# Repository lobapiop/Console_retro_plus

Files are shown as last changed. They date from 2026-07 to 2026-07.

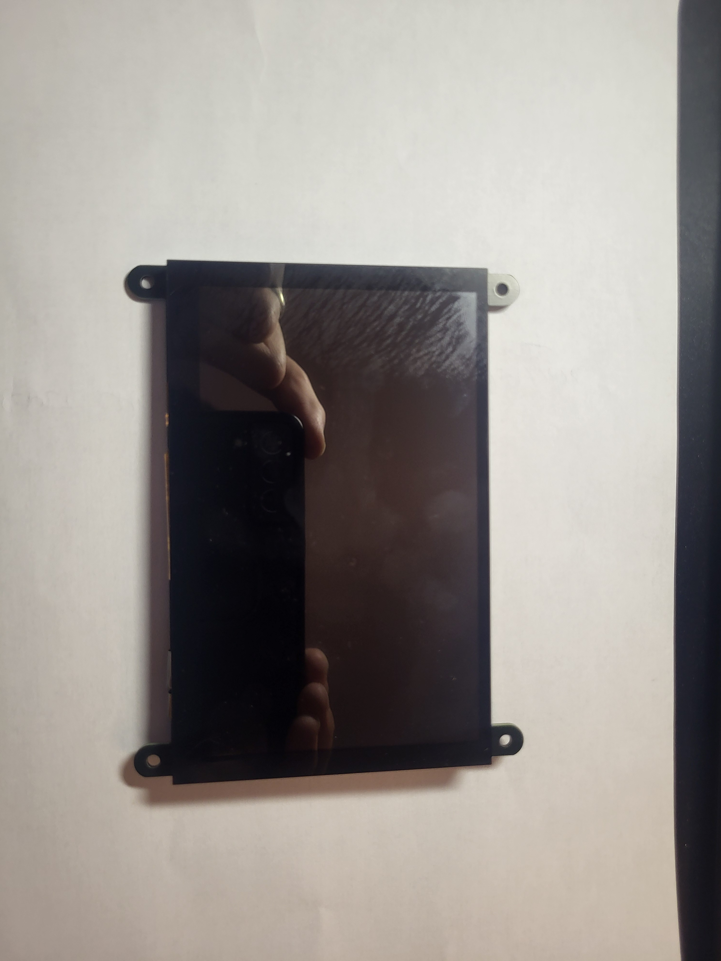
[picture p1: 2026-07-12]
Project-CRP/docs/08-Photos/ET001/face_avant_ecran.jpg

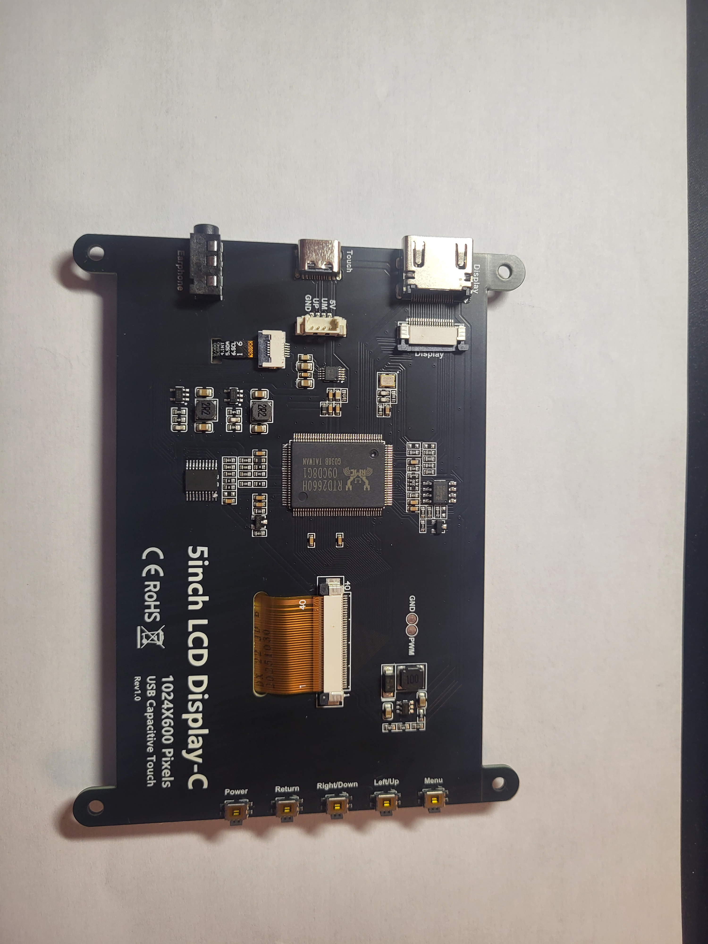
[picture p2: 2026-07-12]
Project-CRP/docs/08-Photos/ET001/face_arriere_ecran.jpg

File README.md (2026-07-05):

# Project CRP - Console Retro Plus

## Présentation

Project CRP (Console Retro Plus) est un projet open source ayant pour objectif de concevoir une console portable de rétrogaming basée sur un Raspberry Pi 5.

Le projet ne consiste pas simplement à intégrer un Raspberry Pi dans un boîtier imprimé en 3D. L'objectif est de développer une console portable fiable, ergonomique, maintenable et entièrement documentée.

Chaque décision de conception est justifiée, documentée et versionnée afin de permettre à toute personne de reproduire ou d'améliorer le projet.

---

## Objectifs

* Concevoir une console portable de qualité.
* Fournir une documentation complète.
* Utiliser des composants standards et facilement disponibles.
* Concevoir un boîtier robuste et facilement réparable.
* Centraliser tous les fichiers de conception dans un dépôt Git unique.
* Rendre le projet reproductible par la communauté.

---

## Caractéristiques principales

* Raspberry Pi 5 (4 Go)
* Écran IPS 5 pouces
* Batocera
* Wi-Fi et Bluetooth intégrés
* Dock HDMI + USB-C
* Recharge USB-C Power Delivery
* Batterie offrant environ 6 heures d'autonomie
* Deux joysticks Hall Effect
* D-Pad
* Boutons ABXY
* Gâchettes L1/L2 et R1/R2
* Haut-parleurs stéréo
* Prise casque 3,5 mm
* Microphone intégré
* Ventilateur intégré (gestion configurable)
* Boîtier imprimé en PETG
* Architecture orientée maintenance

---

## Philosophie du projet

Project CRP repose sur quelques principes simples :

* documenter chaque décision ;
* privilégier la qualité à la compacité ;
* rendre chaque pièce remplaçable ;
* limiter le câblage manuel au strict nécessaire ;
* utiliser des composants standard autant que possible.

---

## Méthodologie

Le projet est développé selon les étapes suivantes :

1. Cahier des charges
2. Architecture matérielle
3. Choix des composants (BOM)
4. Conception du boîtier
5. Conception électronique
6. Prototype
7. Validation
8. Documentation finale

Chaque étape est validée avant de passer à la suivante.

---

## Arborescence du projet

Le dépôt contient :

* documentation technique ;
* modèles 3D ;
* schémas électroniques ;
* PCB ;
* firmware ;
* configuration logicielle ;
* guides d'assemblage ;
* historique des décisions.

---

## État du projet

Version actuelle : Préparation du projet

Le cahier des charges est en cours de rédaction.

---

## Licence

À définir.

---

Projet développé dans un esprit de partage, d'apprentissage et de qualité.

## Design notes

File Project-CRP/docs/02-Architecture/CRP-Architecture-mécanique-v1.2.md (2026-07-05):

# Project CRP – Architecture mécanique

Version : 1.2

---

# 1. Objectif

Ce document définit l'architecture mécanique de Project CRP.

Il décrit :

* les dimensions cibles ;
* l'implantation générale des commandes ;
* les zones fonctionnelles internes ;
* les principes de maintenance ;
* les contraintes mécaniques.

Il constitue la référence avant la modélisation 3D.

---

# 2. Philosophie de conception

Project CRP privilégie :

* une excellente ergonomie ;
* une maintenance simple ;
* une architecture évolutive ;
* une conception robuste ;
* une documentation complète.

La compacité maximale n'est **pas** un objectif.

Le confort d'utilisation et la réparabilité sont prioritaires.

---

# 3. Règles CRP

## Règle n°1

Une architecture ne sera complexifiée que si un bénéfice technique clairement identifié le justifie.

Cela concerne notamment :

* le nombre de PCB ;
* le nombre de connecteurs ;
* le nombre de nappes ;
* les mécanismes particuliers.

---

## Règle n°2

Chaque élément extérieur de la console doit avoir une justification ergonomique ou fonctionnelle.

Son emplacement ne doit jamais être choisi uniquement pour des raisons esthétiques ou par imitation d'une autre console.

Avant de valider son implantation, les questions suivantes doivent être posées :

* est-il facilement accessible ?
* risque-t-il d'être actionné involontairement ?
* simplifie-t-il la maintenance ?
* simplifie-t-il la conception ?
* améliore-t-il l'expérience utilisateur ?

---

# 4. Dimensions cibles

Objectifs actuels :

* Largeur : 245 à 255 mm
* Hauteur : environ 110 mm
* Épaisseur : 25 à 30 mm (hors joysticks)

Poids cible :

* inférieur à 600 g

Ces dimensions pourront évoluer au cours du projet.

---

# 5. Implantation générale

## Façade

```text
┌────────────────────────────────────────────────────────────┐

        L1   L2                          R1   R2

                    Sortie d'air

 D-Pad                                   X   Y

 Stick G                               Stick D

               ┌───────────────────┐
               │                   │
               │   Écran IPS 5"    │
               │                   │
               └───────────────────┘

               Start        Select

────────────────────────────────────────────────────────────

 micro-HDMI   USB-C   Jack   Microphone

└────────────────────────────────────────────────────────────┘
```

Le dock utilisera uniquement les connecteurs situés sur la tranche inférieure.

---

# 6. Vue supérieure

```text
┌────────────────────────────────────────────────────────────┐

L1   L2

          microSD

          Power   ● LED RGB

          Volume +

          Volume -

                             R1   R2

└────────────────────────────────────────────────────────────┘
```

Le dessus de la console regroupe :

* le bouton Power ;
* la LED RGB ;
* les boutons Volume ;
* le lecteur microSD.

Cette disposition évite les appuis involontaires pendant le jeu.

---

# 7. Vue arrière

La face arrière comprend :

* les vis d'ouverture ;
* les entrées d'air ;
* le bouton RESET (accessible avec un trombone).

Le bouton RESET est destiné au développement et aux cas exceptionnels.

---

# 8. Architecture interne

L'organisation interne est définie par zones fonctionnelles.

De l'avant vers l'arrière :

1. coque avant ;
2. écran IPS ;
3. cartes de commandes ;
4. Raspberry Pi 5 ;
5. système de refroidissement ;
6. batterie LiPo ;
7. module d'alimentation ;
8. coque arrière.

Le nombre définitif de PCB sera déterminé ultérieurement.

---

# 9. Batterie

Objectifs :

* autonomie cible : environ 6 heures ;
* batterie remplaçable ;
* connecteur démontable ;
* remplacement sans dessoudage.

La batterie devra être centrée afin d'équilibrer le poids.

---

# 10. Refroidissement

Toutes les versions de Project CRP intégreront un ventilateur.

Le boîtier devra prévoir :

* une entrée d'air ;
* une sortie d'air ;
* un chemin d'air direct vers le Raspberry Pi.

Le ventilateur devra être facilement remplaçable.

Le contrôle intelligent de sa vitesse est une fonctionnalité logicielle optionnelle.

---

# 11. Connecteurs

## Face inférieure

* micro-HDMI
* USB-C Power Delivery
* Jack 3,5 mm
* Microphone

Tous les connecteurs sont regroupés afin de simplifier la conception du dock.

---

## Face supérieure

* Lecteur microSD
* Bouton Power
* LED RGB
* Volume +
* Volume -

---

## Face arrière

* RESET

---

# 12. LED RGB

Une seule LED RGB est utilisée.

Elle est placée à proximité du bouton Power.

Codes retenus :

* Bleu fixe : console allumée.
* Orange fixe : batterie en charge.
* Vert fixe : batterie complètement chargée.
* Rouge fixe : batterie faible.
* Rouge clignotant : batterie critique.
* Blanc bref : confirmation d'un appui sur Power.
* Éteinte : console éteinte (hors recharge).

Aucune LED Bluetooth n'est prévue.

Les informations Bluetooth seront affichées directement par Batocera.

---

# 13. Maintenance

Objectif :

Ouverture complète de la console en moins de cinq minutes.

Ordre souhaité :

1. retirer les vis arrière ;
2. ouvrir la coque ;
3. débrancher la batterie ;
4. accéder immédiatement aux principaux composants.

Les éléments suivants devront être remplaçables :

* batterie ;
* Raspberry Pi ;
* ventilateur ;
* écran ;
* joysticks ;
* haut-parleurs.

Le démontage ne devra nécessiter aucun collage.

---

# 14. Fixations

Le boîtier utilisera :

* des vis métriques standard ;
* des inserts filetés en laiton.

Le collage sera évité autant que possible.

---

# 15. Cheminement des câbles

Les câbles devront :

* être les plus courts possible ;
* être guidés dans des logements dédiés ;
* ne pas gêner la circulation de l'air ;
* ne jamais être pincés lors de la fermeture du boîtier.

---

# 16. Dock

Le dock est volontairement simple.

Fonctions :

* alimentation USB-C ;
* sortie HDMI ;
* LED de présence d'alimentation.

Aucun port USB supplémentaire n'est prévu dans la première version.

---

# 17. Évolutivité

L'architecture devra permettre ultérieurement :

* un changement de batterie ;
* un changement de ventilateur ;
* un RP2040 intégré sur PCB ;
* une évolution du dock.

---

# 18. Points restant à valider

Les éléments suivants seront définis lors des études techniques :

* référence exacte de l'écran ;
* référence de la batterie ;
* référence des joysticks Hall Effect ;
* référence du ventilateur ;
* architecture définitive des PCB.

Aucune décision sur le nombre final de PCB ne sera prise avant la fin des études techniques.

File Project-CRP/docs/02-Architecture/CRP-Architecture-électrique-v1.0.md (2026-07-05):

# Project CRP - Architecture électrique

Version : 1.0

---

# 1. Objectif

Ce document décrit l'architecture électrique générale de Project CRP.

Il définit les différents modules électriques, leurs responsabilités ainsi que les interfaces de communication entre eux.

Il ne constitue pas un schéma électronique mais la référence fonctionnelle qui guidera la conception des futurs PCB.

---

# 2. Vue d'ensemble

```text
                        Chargeur USB-C PD
                               │
                               ▼
                     Module Power / BMS
                               │
             ┌─────────────────┴──────────────────┐
             │                                    │
             ▼                                    ▼
      Batterie LiPo                    Alimentation 5V
             │                                    │
             │                              Raspberry Pi 5
             │                                    │
             │        ┌───────────────────────────┼─────────────────────────────┐
             │        │                           │                             │
             ▼        ▼                           ▼                             ▼
        Jauge batterie RP2040                 HDMI                       USB / GPIO
                 │                             │                             │
                 │                             ▼                             ▼
                 │                       Écran IPS                     Audio / Entrées
                 │
                 ▼
         LED - Ventilateur
         Bouton Power
```

---

# 3. Sous-systèmes

## 3.1 Module Power

Responsabilités :

* réception de l'alimentation USB-C ;
* négociation USB-C Power Delivery ;
* recharge de la batterie ;
* alimentation simultanée du système et de la batterie (Power Path) ;
* protections électriques.

Ce module constitue le cœur de l'alimentation de la console.

---

## 3.2 Batterie

Objectifs :

* batterie LiPo remplaçable ;
* autonomie cible : 6 heures ;
* connecteur démontable.

Le choix définitif de la capacité sera réalisé lors de la BOM.

---

## 3.3 Raspberry Pi 5

Le Raspberry Pi assure :

* Batocera ;
* les émulateurs ;
* le réseau ;
* la vidéo ;
* l'audio logiciel.

Le Raspberry Pi ne pilote pas directement l'alimentation générale.

---

## 3.4 RP2040

Le RP2040 est le contrôleur matériel.

Il reste alimenté indépendamment du Raspberry Pi.

Il pilote notamment :

* bouton Power ;
* LED d'état ;
* ventilateur ;
* surveillance batterie ;
* démarrage et arrêt du Raspberry Pi.

Prototype V0 :

* Raspberry Pi Pico.

Version V1/V2 :

* RP2040 intégré au PCB principal.

---

## 3.5 Écran

Connexion :

HDMI

Alimentation :

5 V

L'écran est indépendant du RP2040.

---

## 3.6 Audio

Comprend :

* amplificateur ;
* deux haut-parleurs ;
* prise jack ;
* microphone.

Le détail de l'architecture audio sera défini dans une version ultérieure.

---

## 3.7 Ventilateur

Ventilateur 5 V.

Piloté par le RP2040.

La vitesse pourra être :

* fixe ;
* automatique ;
* configurable.

---

# 4. Interfaces

| Interface | Utilisation |
| --- | --- |
| HDMI | Écran interne |
| micro-HDMI | Téléviseur |
| USB-C PD | Recharge |
| GPIO | Commandes |
| UART (prévu) | Communication Pi ↔ RP2040 |
| I²C (prévu)  | Capteurs éventuels |
| PWM | Ventilateur |
| I²S ou USB | Audio (à confirmer) |

---

# 5. Démarrage

1. Appui sur Power.
2. Le RP2040 active l'alimentation principale.
3. Le Raspberry Pi démarre.
4. Le RP2040 surveille le système.
5. Les LED indiquent l'état de fonctionnement.

---

# 6. Arrêt

1. Appui sur Power.
2. Le RP2040 demande un arrêt propre au Raspberry Pi.
3. Le Raspberry Pi s'éteint.
4. Le RP2040 coupe l'alimentation principale.

En cas de blocage :

* un appui long forcera l'extinction.

---

# 7. Recharge

Le système devra permettre :

* recharge console éteinte ;
* recharge console allumée ;
* utilisation pendant la recharge ;
* branchement ou débranchement du chargeur sans extinction.

---

# 8. Dock

Le dock est entièrement passif.

Il fournit :

* alimentation USB-C ;
* sortie HDMI ;
* LED de présence d'alimentation.

Aucun composant actif n'est prévu dans la première version.

---

# 9. Maintenance

Tous les modules devront être indépendants.

Les éléments suivants devront pouvoir être remplacés sans dessoudage :

* batterie ;
* écran ;
* Raspberry Pi ;
* ventilateur ;
* haut-parleurs.

Les connecteurs seront privilégiés lorsque cela est possible.

---

# 10. Évolutions prévues

Les éléments suivants pourront être ajoutés ultérieurement :

* jauge de batterie avancée ;
* profils de ventilation ;
* mode veille amélioré ;
* dock intelligent ;
* intégration complète du RP2040 sur PCB.

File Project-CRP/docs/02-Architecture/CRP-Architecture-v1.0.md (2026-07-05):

# Project CRP - Architecture

Version : 1.0

---

# 1. Objectif

Ce document décrit l'architecture générale de Project CRP.

Il définit les principaux sous-systèmes de la console ainsi que leurs interactions.

L'objectif est de garantir une architecture modulaire, facilement maintenable et évolutive.

---

# 2. Vue d'ensemble

```
                        +----------------------+
                        |    Raspberry Pi 5    |
                        |        4 Go          |
                        +----------+-----------+
                                   |
        +------------+-------------+-------------+--------------+
        |            |             |             |              |
        |            |             |             |              |
     HDMI        USB 2.0        GPIO        Bluetooth       Wi-Fi
        |            |             |
        |            |             |
        |        RP2040        Boutons
        |            |
        |            |
        |     Batterie / LEDs
        |
    Ecran IPS
```

Le Raspberry Pi constitue le cœur du système.

Tous les éléments périphériques sont organisés autour de lui.

---

# 3. Modules principaux

## Module de calcul

Fonction :

* exécuter Batocera ;
* faire fonctionner les émulateurs ;
* gérer l'affichage ;
* gérer les communications réseau.

Composant principal :

* Raspberry Pi 5 (4 Go)

---

## Module d'affichage

Fonction :

* affichage principal de la console.

Caractéristiques :

* écran IPS 5 pouces ;
* interface HDMI.

L'écran devra être facilement remplaçable.

---

## Module de commande

Fonction :

* lecture des commandes utilisateur.

Il comprend :

* D-Pad
* ABXY
* Start
* Select
* Volume
* Power
* L1
* L2
* R1
* R2
* deux joysticks Hall Effect

Les commandes seront regroupées sur un ou plusieurs PCB dédiés.

---

## Module audio

Fonction :

* restitution sonore.

Il comprend :

* deux haut-parleurs ;
* une prise casque 3,5 mm ;
* un microphone.

---

## Module alimentation

Fonction :

* alimentation de la console ;
* recharge de la batterie ;
* alimentation pendant la recharge ;
* protection électrique.

Il devra fonctionner de manière totalement transparente pour l'utilisateur.

---

## Module batterie

Objectifs :

* autonomie cible : environ 6 heures ;
* batterie facilement remplaçable ;
* connecteur démontable.

La capacité exacte sera définie ultérieurement.

---

## Module ventilation

Fonction :

* refroidissement du Raspberry Pi.

Le ventilateur sera présent sur toutes les versions.

Le contrôle intelligent restera optionnel.

---

## Module Dock

Fonctions :

* recharge ;
* alimentation ;
* sortie HDMI vers le téléviseur.

Le dock restera volontairement simple.

---

## Module RP2040

Le RP2040 constitue le contrôleur embarqué de la console.

Il sera indépendant du Raspberry Pi.

Fonctions envisagées :

* gestion du bouton Power ;
* surveillance de la batterie ;
* contrôle des LED ;
* contrôle du ventilateur ;
* gestion des sécurités d'alimentation.

Cette architecture permet au Raspberry Pi de rester concentré sur l'émulation.

## Stratégie d'intégration du RP2040

Le RP2040 est retenu comme contrôleur matériel de Project CRP.

Il assurera les fonctions suivantes :

* gestion du bouton Power ;
* extinction propre du Raspberry Pi ;
* contrôle des LED ;
* surveillance de la batterie ;
* contrôle du ventilateur ;
* détection du dock ;
* gestion de certaines sécurités matérielles.

### Prototype V0

Pour le premier prototype, le projet utilisera un **Raspberry Pi Pico** complet.

Ce choix permet :

* de réduire la complexité électronique initiale ;
* de faciliter les tests ;
* de remplacer facilement le module en cas d'erreur ;
* de simplifier le développement du firmware.

### Version V1 / V2

Une fois les fonctions validées, le RP2040 pourra être intégré directement sur un PCB dédié CRP.

Ce choix permettra :

* de réduire l'encombrement ;
* de limiter le câblage ;
* d'améliorer la fiabilité ;
* de rendre l'intégration plus propre.

Cette évolution ne sera réalisée qu'après validation complète du prototype.

---

# 4. Implantation générale

Vue simplifiée :

```
 ___________________________________________

   L1 L2                         R1 R2

+-------------------------------------------+

|                                           |
|               Ecran IPS 5"                |
|                                           |

| DPad                      X  Y            |
|                           A  B            |

| Stick G        Start  Select     Stick D  |

+-------------------------------------------+

| micro-HDMI | USB-C | Jack | Microphone    |

---------------------------------------------
```

Le Raspberry Pi sera implanté derrière l'écran.

La batterie sera placée derrière le Raspberry Pi.

Les cartes boutons seront situées de chaque côté.

---

# 5. Philosophie de maintenance

Toutes les pièces devront être remplaçables.

Ordre de démontage souhaité :

1. Retrait de la coque arrière.
2. Déconnexion de la batterie.
3. Accès au Raspberry Pi.
4. Accès aux haut-parleurs.
5. Accès aux joysticks.
6. Accès aux cartes boutons.

Aucune pièce ne devra être collée.

---

# 6. Architecture logicielle

Le Raspberry Pi exécutera :

* Batocera ;
* les émulateurs ;
* l'interface utilisateur.

Le RP2040 exécutera :

* la gestion matérielle ;
* le contrôle du ventilateur ;
* la surveillance de la batterie ;
* les LED.

Les deux systèmes communiqueront via une interface série (UART) ou USB, à déterminer lors de la conception électronique.

---

# 7. Évolutivité

L'architecture doit permettre :

* le remplacement de la batterie ;
* le remplacement de l'écran ;
* le remplacement des joysticks ;
* l'évolution du firmware RP2040 ;
* l'amélioration du dock.

---

# 8. Principes retenus

Le projet suit les principes suivants :

* simplicité ;
* robustesse ;
* modularité ;
* maintenance ;
* documentation complète.

Chaque sous-système devra pouvoir être testé indépendamment avant l'assemblage final.

---

# 9. Travaux suivants

Les prochaines étapes seront :

* choix des composants ;
* définition du système batterie ;
* définition du système audio ;
* définition des connecteurs ;
* conception du boîtier 3D ;
* réalisation de la nomenclature officielle (BOM).

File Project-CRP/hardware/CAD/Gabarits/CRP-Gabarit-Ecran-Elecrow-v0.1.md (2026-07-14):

# Objectif du gabarit :

Créer une représentation mécanique simplifiée mais dimensionnellement fiable du module écran Elecrow afin de préparer son intégration dans Project CRP.

Le gabarit sert à valider l’encombrement, les fixations, la zone visible, les connecteurs, les nappes fragiles et les volumes de dégagement nécessaires avant toute conception de coque complète.

Module complet : 121,31 × 95,47 × 10 mm
Rectangle écran physique : 121,31 × 75,65 mm
Zone active visible : environ 108 × 64,8 mm
Trous de fixation : Ø 3 mm
Trous hauts : environ Y = 5 mm
Trous bas : environ Y = 91 mm
Profondeur de réservation avec câbles droits : 65 mm
Câbles coudés nécessaires : oui
Zones FPC : à protéger

1. créer le gabarit 2D simple du module ;
2. placer les quatre trous de fixation ;
3. placer la zone écran visible ;
4. ajouter les volumes interdits pour les connecteurs ;
5. ajouter les zones fragiles FPC ;
6. extruder en volume simple 3D ;
7. vérifier si ça rentre dans l’enveloppe CRP cible ;
8. documenter les réserves.

# Données 
Module complet :
121,31 mm × 95,47 mm × 10 mm

Rectangle écran physique :
121,31 mm × 75,65 mm

Zone active visible :
environ 108 mm × 64,8 mm

Trous de fixation :
diamètre 3 mm

Positions des trous :
T1 : X = 5 mm, Y = 5 mm
T2 : X = 117,57 mm, Y = 5 mm
T3 : X = 5 mm, Y = 91 mm
T4 : X = 117,57 mm, Y = 91 mm

# Repère

Origine = coin supérieur gauche du module
X = vers la droite
Y = vers le bas
Z = épaisseur

T1 haut gauche : X = 5 mm, Y = 95,47 - 5 = 90,47 mm
T2 haut droit : X = 117,57 mm, Y = 90,47 mm
T3 bas gauche : X = 5 mm, Y = 95,47 - 91 = 4,47 mm
T4 bas droit : X = 117,57 mm, Y = 4,47 mm

Position verticale de la zone écran physique à confirmer

| Élément | Mesure |
|---|---:|
| Largeur totale avec pattes | 121,31 mm |
| Hauteur totale avec pattes | 95,47 mm |
| Largeur corps principal sans pattes | 121,31 mm |
| Hauteur corps principal sans pattes | 78 mm |
| Dépassement patte gauche | 9 mm |
| Dépassement patte droite | 9 mm |
| Dépassement patte haute | 9 mm |
| Dépassement patte basse | 9 mm |
| Largeur d’une patte | 7.5 mm |
| Diamètre trou fixation | 3 mm |

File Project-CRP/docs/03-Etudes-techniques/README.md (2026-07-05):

# Études techniques

Ce dossier regroupe les études techniques de conception du projet Project CRP.

## Index des études

| Ordre | Étude | Fichier | Statut |
| ----- | ----- | --- | --- |
| ET001 | Écran | [ET001-Ecran.md](ET001-Ecran.md) | à faire |
| ET002 | Ergonomie et commandes | [ET002-Ergonomie-commandes.md](ET002-Ergonomie-commandes.md) | à faire |
| ET003 | Implantation mécanique | [ET003-Implantation-mecanique.md](ET003-Implantation-mecanique.md) | à faire |
| ET004 | Batterie et alimentation | [ET004-Batterie-alimentation.md](ET004-Batterie-alimentation.md) | à faire |
| ET005 | Audio | [ET005-Audio.md](ET005-Audio.md) | à faire |
| ET006 | Refroidissement | [ET006-Refroidissement.md](ET006-Refroidissement.md) | à faire |
| ET007 | RP2040 | [ET007-RP2040.md](ET007-RP2040.md) | à faire |
| ET008 | Dock | [ET008-Dock.md](ET008-Dock.md) | à faire |

## Notes

- Les études sont prévues pour évoluer au fur et à mesure du prototypage.
- Les fichiers peuvent être enrichis avec des schémas, mesures et décisions de conception.

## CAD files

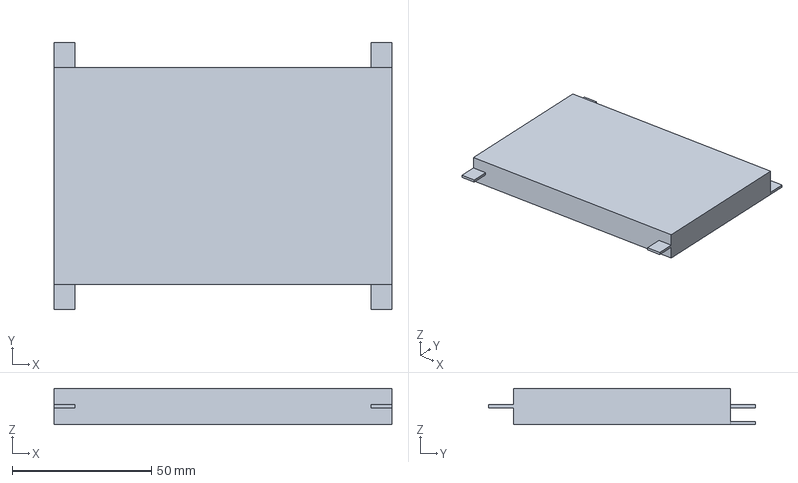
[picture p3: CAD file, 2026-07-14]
Project-CRP/hardware/CAD/Gabarits/CRP-Gabarit-Ecran-Elecrow.FCStd
121.3 x 96.0 x 13.0 mm

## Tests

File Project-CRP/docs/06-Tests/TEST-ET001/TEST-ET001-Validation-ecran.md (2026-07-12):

# Project CRP – TEST-ET001 – Validation du module d’affichage

Version : 0.1  
Statut : à finalisé après l'arrivé du test USB
Étude associée : ET001 – Module d’affichage  
Composant testé : Elecrow 5inch IPS HD Display-C 1024×600  
Référence attendue : DLH04950B  
Plateforme : Raspberry Pi 5 – 4 Go  
Système : Batocera  

---

# 1. Objet

Ce document définit le protocole de validation du module d’affichage Elecrow retenu comme candidat prioritaire pour Project CRP.

L’objectif est de vérifier expérimentalement :

- la conformité du produit reçu ;
- sa compatibilité avec le Raspberry Pi 5 ;
- sa compatibilité avec Batocera ;
- la qualité réelle de l’affichage ;
- la stabilité de fonctionnement ;
- le fonctionnement du tactile ;
- le comportement de la sortie TV ;
- son intégration mécanique préliminaire ;
- son aptitude à devenir l’écran définitif de Project CRP.

La validation finale de l’écran ne doit pas reposer uniquement sur les caractéristiques commerciales ou les avis disponibles.

---

# 2. Périmètre

Le présent protocole couvre :

- l’inspection visuelle du module ;
- le relevé des références ;
- le premier branchement ;
- le premier démarrage ;
- la détection de la résolution ;
- l’utilisation de Batocera ;
- l’affichage des jeux rétro ;
- l’émulation Nintendo DS ;
- le tactile ;
- la sortie HDMI vers un téléviseur ;
- la stabilité thermique ;
- la consommation de l’écran, si un appareil de mesure est disponible ;
- les principales dimensions mécaniques.

Le protocole ne couvre pas encore :

- l’alimentation sur batterie ;
- l’autonomie finale de la console ;
- l’intégration dans la coque ;
- l’électronique de gestion d’alimentation ;
- le dock définitif ;
- la carte de commandes ;
- l’audio définitif de la console.

---

# 3. Critères de décision

À la fin des essais, le module recevra l’un des statuts suivants :

| Statut | Signification |
|---|---|
| Validé | Le module répond aux exigences principales de Project CRP |
| Validé sous réserve | Le module est utilisable, mais des limitations restent à traiter |
| Test complémentaire requis | Les résultats sont insuffisants pour prendre une décision |
| Rejeté | Le module présente une incompatibilité ou une contrainte majeure |

Un défaut critique entraîne normalement le rejet du module.

Exemples de défauts critiques :

- absence d’affichage sous Batocera ;
- image instable ou fortement déformée ;
- impossibilité d’utiliser la résolution native ;
- panne après échauffement ;
- encombrement mécanique incompatible ;
- câblage interne irréalisable ;
- incompatibilité majeure avec la sortie TV.

---

# 4. Matériel nécessaire

## 4.1 Matériel principal

| Élément | Requis | Disponible | Remarque |
|---|---|---|---|
| Raspberry Pi 5 – 4 Go | Oui |  | Plateforme cible CRP |
| Refroidisseur actif pour Raspberry Pi 5 | Oui |  | À installer avant les tests prolongés |
| Alimentation USB-C adaptée au Pi 5 | Oui |  | Alimentation officielle recommandée |
| Carte microSD | Oui |  | 64 Go minimum recommandé |
| Batocera compatible Raspberry Pi 5 | Oui |  | Version à noter |
| Écran Elecrow 5 pouces 1024×600 | Oui |  | Référence à confirmer |
| Câble micro-HDMI vers HDMI | Oui |  | Pour l’écran |
| Câble USB-A vers USB-C | Oui |  | Alimentation et éventuellement tactile |
| Chargeur USB 5 V | Oui |  | 1 A minimum, 2 A recommandé |
| Manette PS4 ou PS5 | Oui |  | Connexion USB pour le premier test |
| Téléviseur ou moniteur HDMI | Pour test TV |  |  |
| Second câble micro-HDMI vers HDMI | Pour test TV |  |  |

## 4.2 Matériel de mesure facultatif

| Élément | Utilité |
|---|---|
| Pied à coulisse | Mesure des dimensions du module |
| Règle métallique | Contrôle approximatif des dimensions |
| Testeur USB | Mesure de la tension, du courant et de la puissance |
| Multimètre | Vérifications électriques complémentaires |
| Thermomètre infrarouge | Mesure approximative des températures |
| Appareil photo ou téléphone | Documentation du test |

---

# 5. Informations générales du test

| Information | Valeur |
|---|---|
| Date du test | 2026-07-12 |
| Testeur | Lobapiop |
| Version de Batocera | batocera-bcm2712-43.1-20260529 |
| Modèle du Raspberry Pi | PI 5 |
| Quantité de mémoire | 4Gbi |
| Référence de l’écran | QDtech MPI5001 |
| Référence indiquée sur le PCB |  |
| Référence indiquée sur l’emballage | 5inch HD Diplay-C |
| Type de carte microSD | 64go |
| Type d’alimentation du Pi | Origine |
| Type d’alimentation de l’écran | Origine |
| Téléviseur utilisé | MSI optix MAG241CV |
| Version du firmware Raspberry Pi, si disponible |  |

---

# 6. Précautions

Avant tout branchement :

1. poser le Raspberry Pi et l’écran sur une surface non conductrice ;
2. ne pas poser les cartes électroniques sur du métal ;
3. installer le refroidisseur actif sur le Raspberry Pi ;
4. vérifier l’orientation des connecteurs ;
5. effectuer les branchements hors tension ;
6. ne pas forcer les prises HDMI ou USB-C ;
7. éviter de toucher directement les composants lorsque le système est alimenté ;
8. ne pas placer d’objet conducteur sous les cartes ;
9. vérifier que le chargeur de l’écran fournit une tension de 5 V ;
10. ne pas utiliser de câble visiblement endommagé.

Pour les premiers essais, le Raspberry Pi et l’écran doivent être alimentés séparément.

---

# 7. Schéma de branchement initial

```text
Alimentation officielle USB-C
            │
            ▼
     Raspberry Pi 5
            │
            │ micro-HDMI vers HDMI
            ▼
      Écran Elecrow

Chargeur USB 5 V
            │
            │ USB-A vers USB-C
            ▼
      Écran Elecrow

Manette PS4 ou PS5
            │
            │ USB
            ▼
     Raspberry Pi 5
```

# 8.Décision :

L’écran Elecrow 5 pouces 1024×600 est retenu comme candidat prioritaire pour Project CRP.

Statut :

Validé sous réserve.

Score après essais :

8,2 / 10.

Réserves restantes :

- consommation électrique réelle non mesurée ;
- câbles droits incompatibles avec la coque cible ;
- câbles coudés ou adaptation interne nécessaires ;
- protection obligatoire des nappes FPC ;
- validation mécanique finale à réaliser dans FreeCAD.

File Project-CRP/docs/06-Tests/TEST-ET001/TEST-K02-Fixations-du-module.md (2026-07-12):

# Project CRP – TEST-K02 – Fixations du module

Version : 0.1  
Statut : réalisé
Étude associée : ET001 – Module d’affichage  
Composant testé : Elecrow 5inch IPS HD Display-C 1024×600  
Référence attendue : DLH04950B  
Plateforme : Raspberry Pi 5 – 4 Go  
Système : Batocera  

---

## 1. Objectif

Relever les trous et entraxes nécessaires au montage mécanique.

## 2. Procédure

1. Numéroter les trous.
2. Mesurer leur diamètre.
3. Mesurer les entraxes horizontaux et verticaux.
4. Mesurer leur distance aux bords de référence.
5. Photographier le module avec les points repérés.

## 3. Résultats

T1 = trou haut gauche
T2 = trou haut droit
T3 = trou bas gauche
T4 = trou bas droit

Diamètre trou T1 : 3 mm
Diamètre trou T2 : 3 mm
Diamètre trou T3 : 3 mm
Diamètre trou T4 : 3 mm

Entraxe horizontal supérieur : T1 → T2
Entraxe horizontal inférieur : T3 → T4
Entraxe vertical gauche : T1 → T3
Entraxe vertical droit : T2 → T4

| Élément | Mesure |
|---|---:|
| Entraxe horizontal supérieur | 112.75 mm |
| Entraxe horizontal inférieur | 112.75 mm |
| Entraxe vertical gauche | 85.33 mm |
| Entraxe vertical droit | 85.33 mm |

T1 : centre à 5 mm du bord gauche, 5 mm du bord supérieur
T2 : centre à 117.57 mm du bord gauche, 5 mm du bord supérieur
T3 : centre à 5 mm du bord gauche, 91 mm du bord supérieur
T4 : centre à 117.57 mm du bord gauche, 91 mm du bord supérieur

Y a-t-il un composant proche ? non tout est à l'extérieur
Y a-t-il assez de place pour une tête de vis ? oui
Y a-t-il assez de place pour une entretoise ? oui
Le trou est-il métallisé ? non c'est du PCB
Le trou traverse-t-il seulement le PCB ? Oui
La vis risque-t-elle de toucher un composant ? Non

## 4. Observations

- présence d’inserts :  Non
- possibilité d’utiliser des entretoises :  oui
- zone libre autour des trous :  Oui
- risque de contact avec des composants :  Non

## 5. Conclusion

Fixations directement utilisables : Oui 

Remarques :

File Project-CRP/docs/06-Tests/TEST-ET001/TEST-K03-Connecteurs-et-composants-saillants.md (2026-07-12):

# Project CRP – TEST-K03 – Connecteurs et composants saillants

Version : 0.1  
Statut : réalisé
Étude associée : ET001 – Module d’affichage  
Composant testé : Elecrow 5inch IPS HD Display-C 1024×600  
Référence attendue : DLH04950B  
Plateforme : Raspberry Pi 5 – 4 Go  
Système : Batocera  

---

## 1. Objectif

Déterminer les volumes à réserver autour des connecteurs, boutons et composants arrière.

## 2. Procédure

1. Repérer chaque connecteur.
2. Mesurer sa position depuis deux bords de référence.
3. Mesurer son débord.
4. Brancher les câbles sans alimenter le système.
5. estimer le rayon de courbure et le dégagement nécessaire.

## 3. Résultats

| Connecteur | Débord rigide avec câble branché | Rayon de courbure estimé | Dégagement recommandé |
|---|---:|---:|---:|
| USB-C écran | 40 mm | 10 mm | 55 mm |
| HDMI | 40 mm | 20 mm | 65 mm |
| Jack audio  | 40 mm | 10 mm | 55 mm |
| Connecteur FPC |  |  |  |
| Boutons OSD |  |  |  |
| Composant le plus haut |  |  |  |

## 4. Câblage

| Câble | Connecteur droit/coudé | Rayon minimal observé | Compatible avec la coque cible |
|---|---|---:|---|
| HDMI | Droit | 20mm |  Non  |
| USB-C | Droit | 10mm |  Non |
| Audio | Droit | 10mm  |  Non |

## 5. Conclusion

Profondeur de réservation recommandée :

`65 mm`

Câbles coudés nécessaires : Oui 

Remarques :

Connecteur FPC principal dalle LCD : Oui
Position : centre-bas de la carte
Nappe présente : Oui, nappe orange large
Risque mécanique : élevé
Remarque : ne pas plier fortement, ne pas écraser, prévoir un dégagement dans la coque.

Connecteur FPC Display secondaire : Oui
Position : sous le connecteur HDMI
Nappe présente : Non
Risque mécanique : moyen à élevé
Remarque : zone à protéger, proche du connecteur HDMI.

Petit connecteur FPC secondaire : Oui
Position : partie haute-gauche de la carte, sous la zone earphone / touch
Nappe présente : Oui
Risque mécanique : moyen
Remarque : petite nappe fragile, ne pas mettre en contrainte.

## Connecteurs FPC observés

| Élément | Présence | Position | Remarque |
|---|---|---|---|
| FPC principal dalle LCD | Oui | centre-bas de la carte | grande nappe orange, zone critique |
| FPC Display secondaire | Oui | sous le connecteur HDMI | proche du HDMI, à protéger |
| Petit FPC secondaire | Oui | haut-gauche / zone Touch | petite nappe fragile |
| Connecteur 5V/Uart/GND | Non FPC | haut-centre | connecteur filaire, probablement JST |
| Boutons OSD | Non FPC | bord bas | boutons physiques de réglage écran |

Conclusion :

Le module comporte plusieurs nappes FPC visibles. Ces zones sont mécaniquement sensibles et devront être protégées dans la future coque. Aucun appui direct de la coque, d’une entretoise ou d’un câble ne devra être exercé sur les nappes ou sur leurs connecteurs.

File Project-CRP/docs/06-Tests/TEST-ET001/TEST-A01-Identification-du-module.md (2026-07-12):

# Project CRP – TEST-A01 – Identification du module

Version : 0.1  
Statut : réalisé 
Étude associée : ET001 – Module d’affichage  
Composant testé : Elecrow 5inch IPS HD Display-C 1024×600  
Référence attendue : DLH04950B  
Plateforme : Raspberry Pi 5 – 4 Go  
Système : Batocera  

---

## 1. Objectif

Vérifier que le produit reçu correspond au module commandé et qu’il ne présente aucun dommage visible.

## 2. Matériel nécessaire

- module Elecrow reçu ; 
- emballage et accessoires ; 
- téléphone ou appareil photo ;
- plan ou fiche produit disponible.

## 3. Procédure

1. Ne pas alimenter le module.
2. Photographier l’emballage, la face avant, la face arrière et les connecteurs.
3. Relever toutes les références présentes sur l’emballage et le PCB.
4. Vérifier visuellement la dalle, le PCB, les connecteurs et les nappes.
5. Comparer le contenu reçu avec la commande.

## 4. Résultats

| Contrôle | Observation | Conforme |
|---|---|---|
| Marque Elecrow présente |  | Oui  |
| Diagonale annoncée de 5 pouces |  | Oui |
| Résolution annoncée de 1024×600 |  | Oui |
| Référence DLH04950B présente |  |  Non trouvée |
| Entrée HDMI présente |  | Oui  |
| Connecteur USB-C présent |  | Oui |
| Tactile présent |  | Oui / Non |
| PCB sans dommage visible |  | Oui  |
| Dalle sans fissure |  | Oui  |
| Connecteurs non déformés |  | Oui |
| Accessoires conformes |  | Oui  |

## 5. Critères de réussite

- aucun dommage visible ;
- connecteurs intacts ;
- caractéristiques principales conformes ;
- absence d’erreur évidente de modèle.

## 6. Conclusion

Résultat :  Ok

Références relevées :

Remarques : Je n'ai pas trouvé la référence. 

Photos associées :

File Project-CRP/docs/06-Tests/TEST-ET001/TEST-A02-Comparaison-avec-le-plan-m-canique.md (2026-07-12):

# Project CRP – TEST-A02 – Comparaison avec le plan mécanique

Version : 0.1  
Statut : réalisé  
Étude associée : ET001 – Module d’affichage  
Composant testé : Elecrow 5inch IPS HD Display-C 1024×600  
Référence attendue : DLH04950B  
Plateforme : Raspberry Pi 5 – 4 Go  
Système : Batocera  

---

## 1. Objectif

Déterminer si le plan mécanique précédemment trouvé correspond réellement au module reçu.

## 2. Matériel nécessaire

- module Elecrow ;
- plan mécanique trouvé ;
- règle ou pied à coulisse ;
- appareil photo.

## 3. Procédure

1. Comparer la forme générale du PCB.
2. Comparer la position et l’orientation des connecteurs.
3. Compter les boutons et les trous de fixation.
4. Comparer les dimensions générales.
5. Photographier chaque différence.

## 4. Résultats

| Élément comparé | Identique | Différent | Remarque |
|---|---|---|---|
| Forme générale du PCB | Identique |  |  |
| Position du port HDMI | Identique |  |  |
| Position du port USB-C | Identique |  |  |
| Nombre de boutons | Identique |  |  |
| Position des boutons | Identique |  |  |
| Nombre de trous de fixation | Identique |  |  |
| Position des trous | Identique |  |  |
| Forme des composants arrière | Identique |  |  |
| Dimensions générales | Identique |  |  |

## 5. Décision documentaire

Plan correspondant au produit :

- [X] Oui, correspondance confirmée
- [ ] Correspondance partielle
- [ ] Non, modèle différent
- [ ] Impossible à déterminer

Plan utilisable pour FreeCAD :

- [ ] Oui
- [ ] Non
- [X] Seulement après correction

## 6. Conclusion

Résultat : Réussi 

Corrections à apporter au plan : 
## Mise à jour – Distinction entre hauteur totale et zone écran

Le module Elecrow reçu mesure approximativement :

- longueur horizontale totale : 121,31 mm ;
- hauteur totale du module : 95,47 mm ;
- profondeur approximative : 10 mm ;
- rectangle physique de l’écran : 75,65 mm de hauteur.

La différence entre la hauteur totale du module et le rectangle physique de l’écran est d’environ :

95,47 mm - 75,65 mm = 19,82 mm.

Cette zone supplémentaire semble correspondre principalement à une zone technique liée aux fixations, au PCB ou aux connecteurs, et non à la surface visible de l’écran.

Cette distinction est importante pour Project CRP :

- la façade visible ne doit pas nécessairement exposer les 95,47 mm complets ;
- l’ouverture esthétique peut être dimensionnée autour de la zone écran ;
- la zone technique supérieure peut être cachée derrière la coque ;
- l’encombrement interne total reste néanmoins de 95,47 mm.

La contrainte mécanique est donc moins sévère que si toute la hauteur était visible en façade.

La note provisoire d’intégration mécanique de l’Elecrow est corrigée à 8/10.

Le module reste candidat prioritaire sous réserve de validation du câblage, des fixations et des tests d’affichage.

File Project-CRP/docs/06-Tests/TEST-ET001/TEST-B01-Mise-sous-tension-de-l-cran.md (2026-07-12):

# Project CRP – TEST-B01 – Mise sous tension de l’écran

Version : 0.1  
Statut : réalisé
Étude associée : ET001 – Module d’affichage  
Composant testé : Elecrow 5inch IPS HD Display-C 1024×600  
Référence attendue : DLH04950B  
Plateforme : Raspberry Pi 5 – 4 Go  
Système : Batocera  

---

## 1. Objectif

Vérifier que l’écran s’allume normalement lorsqu’il est alimenté seul.

## 2. Précautions

- poser le module sur une surface non conductrice ;
- effectuer les branchements hors tension ;
- utiliser une alimentation USB 5 V ;
- ne pas toucher les composants pendant l’essai.

## 3. Procédure

1. Connecter le câble USB-C à l’écran.
2. Connecter le câble à un chargeur USB 5 V.
3. Mettre le chargeur sous tension.
4. Observer le module pendant au moins 30 secondes.
5. Couper immédiatement l’alimentation en cas d’odeur, de bruit ou de chauffe anormale.

## 4. Résultats

| Observation | Résultat |
|---|---|
| Rétroéclairage visible | Oui |
| Message d’absence de signal | Oui |
| LED d’état éventuelle | je n'ai pas vu de led |
| Bruit anormal |non |
| Odeur anormale | non |
| Chauffe immédiate anormale | non |

## 5. Critère de réussite

L’écran s’allume sans comportement dangereux ou anormal.

## 6. Conclusion

Résultat : Réussi 

Remarques :

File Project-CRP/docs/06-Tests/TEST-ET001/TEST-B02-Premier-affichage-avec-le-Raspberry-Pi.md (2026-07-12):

# Project CRP – TEST-B02 – Premier affichage avec le Raspberry Pi

Version : 0.1  
Statut : réalisé 
Étude associée : ET001 – Module d’affichage  
Composant testé : Elecrow 5inch IPS HD Display-C 1024×600  
Référence attendue : DLH04950B  
Plateforme : Raspberry Pi 5 – 4 Go  
Système : Batocera  

---

## 1. Objectif

Vérifier que le Raspberry Pi 5 affiche correctement la séquence de démarrage et Batocera sur l’écran.

## 2. Branchement

```text
Alimentation Pi 5 ──► Raspberry Pi 5
Raspberry Pi 5 ── micro-HDMI/HDMI ──► Elecrow
Chargeur USB 5 V ── USB-C ──► Elecrow
Manette PS4/PS5 ── USB ──► Raspberry Pi 5
```

## 3. Procédure

1. Couper toutes les alimentations.
2. Insérer la microSD Batocera.
3. Brancher le câble HDMI.
4. Alimenter l’écran.
5. Alimenter le Raspberry Pi.
6. Observer toute la séquence pendant au moins deux minutes.

## 4. Résultats

| Point contrôlé | Résultat |
|---|---|
| Logo ou texte visible au démarrage | oui |
| Affichage pendant le chargement | oui |
| Démarrage de Batocera | oui |
| Image centrée | oui |
| Image complète | oui |
| Image stable | oui |
| Couleurs normales | oui |
| Absence de scintillement | oui |
| Absence de lignes parasites | oui |

## 5. Critère de réussite

Batocera apparaît de manière stable et exploitable.

## 6. Conclusion

Résultat : Réussi 

Remarques : je n'ai pas testé sur un jeu DS mais Nintendo 64 (dongkey kong) qui est par défaut sur le système.

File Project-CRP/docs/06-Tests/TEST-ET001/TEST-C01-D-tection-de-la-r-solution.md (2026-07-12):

# Project CRP – TEST-C01 – Détection de la résolution

Version : 0.1  
Statut : réalisé
Étude associée : ET001 – Module d’affichage  
Composant testé : Elecrow 5inch IPS HD Display-C 1024×600  
Référence attendue : DLH04950B  
Plateforme : Raspberry Pi 5 – 4 Go  
Système : Batocera  

---

## 1. Objectif

Vérifier que Batocera utilise une résolution adaptée, idéalement 1024×600 à 60 Hz.

## 2. Procédure

1. Démarrer Batocera.
2. Relever la résolution détectée.
3. Vérifier la fréquence.
4. Vérifier l’orientation.
5. Redémarrer après toute modification.
6. Documenter précisément les paramètres ajoutés.

## 3. Résultats

| Élément | Valeur |
|---|---|
| Résolution détectée | 1024x600 |
| Résolution sélectionnée | 1024x600 |
| Fréquence détectée | 66 |
| Orientation | Paysage  |
| Configuration manuelle nécessaire | Non |
| Fichier modifié | Aucun |
| Paramètres ajoutés | Aucun |

## 4. Critères de réussite

- mode 1024×600 disponible ou mode alternatif sans déformation ;
- proportions correctes ;
- image complète ;
- configuration conservée après redémarrage.

## 5. Conclusion

Résultat : Réussi 

Remarques :

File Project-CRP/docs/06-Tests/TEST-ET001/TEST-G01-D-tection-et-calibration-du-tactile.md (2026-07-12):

# Project CRP – TEST-G01 – Détection et calibration du tactile

Version : 0.1  
Statut : réalisé
Étude associée : ET001 – Module d’affichage  
Composant testé : Elecrow 5inch IPS HD Display-C 1024×600  
Référence attendue : DLH04950B  
Plateforme : Raspberry Pi 5 – 4 Go  
Système : Batocera  

---

## 1. Objectif

Vérifier la détection, l’orientation et la précision du tactile.

## 2. Procédure

1. Connecter l’USB du tactile.
2. Démarrer Batocera.
3. Tester le centre et les quatre coins.
4. Effectuer un glissement.
5. Tester plusieurs pressions rapides.
6. Vérifier l’orientation après toute rotation d’écran.

## 3. Résultats

| Contrôle | Résultat |
|---|---|
| Tactile détecté automatiquement | Oui |
| Coin supérieur gauche correct | Pas testable |
| Coin supérieur droit correct | Pas testable |
| Coin inférieur gauche correct | Ok |
| Coin inférieur droit correct | Ok |
| Centre correct | Ok |
| Glissement correct | Ok |
| Multitouch détecté | Pas testable |
| Calibration nécessaire | Non |
| Orientation tactile correcte | Oui |

## 4. Conclusion

Résultat : Réussi 

Paramètres nécessaires :

Commentaires : Je ne pouvais pas tester les angles pour savoir si tout est ok (pas de bouton disponible sur les angles). Même constat pour le multitouch.

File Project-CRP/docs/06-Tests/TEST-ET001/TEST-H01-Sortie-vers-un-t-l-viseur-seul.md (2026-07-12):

# Project CRP – TEST-H01 – Sortie vers un téléviseur seul

Version : 0.1  
Statut : réalisé 
Étude associée : ET001 – Module d’affichage  
Composant testé : Elecrow 5inch IPS HD Display-C 1024×600  
Référence attendue : DLH04950B  
Plateforme : Raspberry Pi 5 – 4 Go  
Système : Batocera  

---

## 1. Objectif

Vérifier que Batocera fonctionne normalement avec un téléviseur sans l’écran Elecrow comme sortie vidéo.

## 2. Branchement

```text
Raspberry Pi 5 ── micro-HDMI/HDMI ──► Téléviseur
```

## 3. Procédure

1. Éteindre le Raspberry Pi.
2. Déconnecter le signal HDMI de l’Elecrow.
3. Connecter le téléviseur.
4. Démarrer Batocera.
5. Tester l’image, le son et un jeu.

## 4. Résultats

| Contrôle | Résultat |
|---|---|
| Image affichée sur la TV | Oui |
| Résolution correcte | Oui |
| Son HDMI fonctionnel | Oui  |
| Menus lisibles | Oui |
| Jeux fonctionnels | Oui |

## 5. Conclusion

Résultat : Réussi 
Remarques :

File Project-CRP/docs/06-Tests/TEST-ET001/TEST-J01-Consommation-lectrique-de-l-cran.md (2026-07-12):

# Project CRP – TEST-J01 – Consommation électrique de l’écran

Version : 0.1  
Statut : reporté
Étude associée : ET001 – Module d’affichage  
Composant testé : Elecrow 5inch IPS HD Display-C 1024×600  
Référence attendue : DLH04950B  
Plateforme : Raspberry Pi 5 – 4 Go  
Système : Batocera  

---

## 1. Objectif

Mesurer la consommation réelle de l’écran selon sa luminosité et le contenu affiché.

## 2. Matériel nécessaire

- testeur USB mesurant tension, courant et puissance ;
- chargeur USB 5 V ;
- écran Elecrow.

Référence envisagée :

- Testeur USB Amazon B0DGFZ1PP4
- Prix observé : 18,98 €
- Fonctions annoncées : V, A, W, Wh, USB-A, USB-C
- Statut : achat recommandé pour reprise ultérieure du test J01

## 3. Procédure

Placer le testeur USB entre le chargeur et l’écran, puis effectuer chaque mesure après stabilisation.

## 4. Résultats

| État | Tension | Courant | Puissance |
|---|---:|---:|---:|
| Écran sans signal |  |  |  |
| Luminosité minimale |  |  |  |
| Luminosité à 50 % |  |  |  |
| Luminosité maximale |  |  |  |
| Image principalement sombre |  |  |  |
| Image principalement blanche |  |  |  |
| Tactile utilisé |  |  |  |

## 5. Bilan énergétique

Puissance moyenne estimée :

`________ W`

Consommation estimée sur six heures :

`________ Wh`

## 6. Conclusion

Compatible avec l’objectif d’autonomie :

- [ ] Oui
- [ ] Oui, sous réserve
- [ ] Non
- [ ] Données insuffisantes

Remarques :

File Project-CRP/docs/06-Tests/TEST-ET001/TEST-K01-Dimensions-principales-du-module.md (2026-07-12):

# Project CRP – TEST-K01 – Dimensions principales du module

Version : 0.1  
Statut : réalisé  
Étude associée : ET001 – Module d’affichage  
Composant testé : Elecrow 5inch IPS HD Display-C 1024×600  
Référence attendue : DLH04950B  
Plateforme : Raspberry Pi 5 – 4 Go  
Système : Batocera  

---

## 1. Objectif

Relever les dimensions nécessaires au futur gabarit FreeCAD.

## 2. Matériel nécessaire

- pied à coulisse recommandé ;
- règle de secours ;
- module non alimenté ;
- plan mécanique trouvé.

## 3. Précautions

- ne pas serrer fortement le pied à coulisse sur la dalle ;
- ne pas appuyer sur les nappes ;
- mesurer plusieurs fois ;
- noter l’incertitude de mesure.

## 4. Résultats

| Élément | Valeur mesurée | Valeur du plan trouvé | Écart |
|---|---:|---:|---:|
| Largeur hors tout | 122.77 | 121,11 mm | 1.66 |
| Hauteur hors tout | 95.07mm | 77,93 mm | 17.14 |
| Épaisseur de la dalle | 4.07 |  |  |
| Épaisseur du PCB | 7.87 |  |  |
| Profondeur maximale | 13.30 | 13,94 mm | -0.65 |
| Largeur de la zone active | 108.88 | 108 mm | 0.88 |
| Hauteur de la zone active | 66.36 | 64,8 mm | 1.56 |

Instrument utilisé : pied à coulisse

Incertitude estimée : épaisseur de PCB je n'ai pas pris en compte la mousse qui sépare la dalle du PCB.

## 5. Conclusion

Dimensions du plan confirmées : Partiellement

Remarques : voir Incertitudes

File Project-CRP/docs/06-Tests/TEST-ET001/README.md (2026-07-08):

# Project CRP – Cahier de tests ET001

Version : 0.1  
Statut : à exécuter  
Objet : validation expérimentale du module d’affichage Elecrow 5 pouces 1024×600

---

## 1. Ordre recommandé

### Priorité 1 — Identification et premier démarrage

1. TEST-A01
2. TEST-A02
3. TEST-B01
4. TEST-B02
5. TEST-C01
6. TEST-C02
7. TEST-C03

### Priorité 2 — Qualité et usage

8. TEST-D01
9. TEST-D02
10. TEST-D03
11. TEST-D04
12. TEST-E01
13. TEST-E02
14. TEST-E03
15. TEST-F01

### Priorité 3 — Fonctions complémentaires

16. TEST-G01
17. TEST-G02
18. TEST-H01
19. TEST-H02
20. TEST-H03
21. TEST-I01
22. TEST-J01

### Priorité 4 — Relevé mécanique

23. TEST-K01
24. TEST-K02
25. TEST-K03

---

## 2. Fichiers

| Code | Test | Fichier |
|---|---|---|
| TEST-A01 | Identification du module | `TEST-A01-Identification-du-module.md` |
| TEST-A02 | Comparaison avec le plan mécanique | `TEST-A02-Comparaison-avec-le-plan-m-canique.md` |
| TEST-B01 | Mise sous tension de l’écran | `TEST-B01-Mise-sous-tension-de-l-cran.md` |
| TEST-B02 | Premier affichage avec le Raspberry Pi | `TEST-B02-Premier-affichage-avec-le-Raspberry-Pi.md` |
| TEST-C01 | Détection de la résolution | `TEST-C01-D-tection-de-la-r-solution.md` |
| TEST-C02 | Géométrie de l’image | `TEST-C02-G-om-trie-de-l-image.md` |
| TEST-C03 | Redémarrages successifs | `TEST-C03-Red-marrages-successifs.md` |
| TEST-D01 | Luminosité | `TEST-D01-Luminosit.md` |
| TEST-D02 | Couleurs contraste et uniformité | `TEST-D02-Couleurs-contraste-et-uniformit.md` |
| TEST-D03 | Angles de vision | `TEST-D03-Angles-de-vision.md` |
| TEST-D04 | Fluidité et rémanence | `TEST-D04-Fluidit-et-r-manence.md` |
| TEST-E01 | Interface EmulationStation | `TEST-E01-Interface-EmulationStation.md` |
| TEST-E02 | Jeux rétro au format 4 sur 3 | `TEST-E02-Jeux-r-tro-au-format-4-sur-3.md` |
| TEST-E03 | Jeux au format large | `TEST-E03-Jeux-au-format-large.md` |
| TEST-F01 | Affichage Nintendo DS | `TEST-F01-Affichage-Nintendo-DS.md` |
| TEST-G01 | Détection et calibration du tactile | `TEST-G01-D-tection-et-calibration-du-tactile.md` |
| TEST-G02 | Tactile dans un émulateur Nintendo DS | `TEST-G02-Tactile-dans-un-mulateur-Nintendo-DS.md` |
| TEST-H01 | Sortie vers un téléviseur seul | `TEST-H01-Sortie-vers-un-t-l-viseur-seul.md` |
| TEST-H02 | Double sortie HDMI | `TEST-H02-Double-sortie-HDMI.md` |
| TEST-H03 | Déconnexion et reconnexion du téléviseur | `TEST-H03-D-connexion-et-reconnexion-du-t-l-viseur.md` |
| TEST-I01 | Fonctionnement prolongé et température | `TEST-I01-Fonctionnement-prolong-et-temp-rature.md` |
| TEST-J01 | Consommation électrique de l’écran | `TEST-J01-Consommation-lectrique-de-l-cran.md` |
| TEST-K01 | Dimensions principales du module | `TEST-K01-Dimensions-principales-du-module.md` |
| TEST-K02 | Fixations du module | `TEST-K02-Fixations-du-module.md` |
| TEST-K03 | Connecteurs et composants saillants | `TEST-K03-Connecteurs-et-composants-saillants.md` |

---

## 3. Statuts possibles

- **Réussi** : exigences satisfaites.
- **Réussi avec configuration** : fonctionnement validé après réglage documenté.
- **Acceptable avec réserve** : utilisable, mais une limitation doit être suivie.
- **Test complémentaire requis** : résultat insuffisant.
- **Échec** : exigence non satisfaite.
- **Non applicable** : test sans objet pour la configuration évaluée.

---

## 4. Règle de validation

L’écran ne doit être déclaré définitivement validé qu’après :

- réussite du premier affichage ;
- résolution et géométrie correctes ;
- stabilité après redémarrages ;
- qualité d’image jugée suffisante ;
- fonctionnement prolongé sans défaut critique ;
- intégration mécanique jugée possible ;
- absence de blocage majeur pour la sortie TV.

## Ventilateur pendant les tests ET001

Pendant les tests de validation de l’écran, le Raspberry Pi 5 utilisera le refroidisseur actif branché sur le connecteur ventilateur officiel.

Aucune courbe de ventilation personnalisée ne sera configurée dans Batocera pendant ET001.

Objectif :

- garantir un refroidissement suffisant ;
- éviter de confondre un problème thermique avec un problème d’écran ;
- conserver une configuration logicielle simple ;
- reporter l’optimisation du bruit et des courbes de ventilation à l’étude ET006 – Refroidissement.

Le comportement du ventilateur sera simplement observé :

- ventilateur détecté ou non ;
- démarrage automatique ;
- bruit perceptible ;
- température du Raspberry Pi pendant les essais prolongés.

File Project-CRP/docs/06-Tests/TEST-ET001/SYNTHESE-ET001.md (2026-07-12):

# Project CRP – Synthèse des tests ET001

Version : 0.1  
Statut : quasi final – J01 reporté

---

## 1. Informations générales

| Information | Valeur |
|---|---|
| Date du début des essais | 2026-07-06 |
| Date de fin des essais | 2026-07-12 |
| Testeur | Lobapiop |
| Version de Batocera | batocera-bcm2712-43.1-20260529 |
| Modèle du Raspberry Pi | Raspberry Pi 5 – 4 Go |
| Référence de l’écran | QDtech MPI5001 |
| Référence du PCB |  |
| Alimentation du Pi | Origine PI 5 |
| Alimentation de l’écran | Orgine écran |

---

## 2. Résultats

| Test | Résultat | Critique | Action |
|---|---|---|---|
| TEST-A01 – Identification du module | Réussi | Oui |  |
| TEST-A02 – Comparaison avec le plan mécanique | Réussi | Oui | Plan constructeur non retenu comme référence finale |
| TEST-B01 – Mise sous tension de l’écran | Réussi | Oui |  |
| TEST-B02 – Premier affichage avec le Raspberry Pi | Réussi | Oui |  |
| TEST-C01 – Détection de la résolution | Réussi | Oui |  |
| TEST-C02 – Géométrie de l’image | Réussi | Oui |  |
| TEST-C03 – Redémarrages successifs | Réussi | Oui |  |
| TEST-D01 – Luminosité | Réussi | Oui |  |
| TEST-D02 – Couleurs contraste et uniformité | Réussi | Oui |  |
| TEST-D03 – Angles de vision | Réussi | Oui |  |
| TEST-D04 – Fluidité et rémanence | Réussi | Oui |  |
| TEST-E01 – Interface EmulationStation | Réussi | Oui |  |
| TEST-E02 – Jeux rétro au format 4 sur 3 | Réussi | Oui |  |
| TEST-E03 – Jeux au format large | Réussi | Oui |  |
| TEST-F01 – Affichage Nintendo DS | Réussi avec réserve | Oui | Utiliser melonDS et une disposition adaptée |
| TEST-G01 – Détection et calibration du tactile | Réussi | Oui |  |
| TEST-G02 – Tactile dans un émulateur Nintendo DS | Réussi avec réserve | Oui | Utiliser melonDS |
| TEST-H01 – Sortie vers un téléviseur seul | Réussi | Oui |  |
| TEST-H02 – Double sortie HDMI | Réussi | Oui | Comportement documenté |
| TEST-H03 – Déconnexion et reconnexion du téléviseur | Réussi | Oui |  |
| TEST-I01 – Fonctionnement prolongé et température | Réussi | Oui |  |
| TEST-J01 – Consommation électrique de l’écran | Reporté | Non | À faire avec testeur USB |
| TEST-K01 – Dimensions principales du module | Réussi | Oui |  |
| TEST-K02 – Fixations du module | Réussi | Oui |  |
| TEST-K03 – Connecteurs et composants saillants | Réussi avec réserve | Oui | Câbles coudés nécessaires |

## 3. Notes expérimentales

| Critère | Pondération | Note avant essai | Note après essai | Justification après essai |
|---|---:|---:|---:|---|
| Compatibilité Raspberry Pi | 20 % | 8 | 9 | Fonctionne avec Raspberry Pi 5 et Batocera, résolution 1024×600 validée, HDMI fonctionnel, tactile détecté. |
| Intégration mécanique | 20 % | 9 | 7,5 | Dimensions réelles acceptables, fixation possible, mais câbles droits HDMI/USB-C/jack trop encombrants pour la coque cible. Câbles coudés ou adaptation nécessaire. |
| Intégration électronique | 15 % | 8,5 | 8 | Fonctionne correctement, tactile USB reconnu, HDMI OK. Réserve restante sur consommation réelle non mesurée et câblage interne à optimiser. |
| Qualité d’affichage | 20 % | 8 | 9 | Géométrie, couleurs, luminosité, angles de vision et fluidité validés. Très bon résultat pour Project CRP. |
| Maintenance | 10 % | 8 | 8 | Module remplaçable et connectique accessible, mais présence de nappes FPC fragiles à protéger. |
| Pérennité | 10 % | 7 | 7 | Produit disponible et bien adapté, mais dépend d’un module commercial tiers non officiel Raspberry Pi. |
| Documentation | 5 % | 9 | 8,5 | Documentation suffisante, marquages PCB utiles, mais plan mécanique trouvé non conforme au module reçu. Les mesures réelles deviennent prioritaires. |
| **Score pondéré** | **100 %** | **Provisoire** | **8,2 / 10** | Écran validé sous réserve mécanique et alimentation. |

Compatibilité Raspberry Pi : 9 × 20 % = 1,80
Intégration mécanique : 7,5 × 20 % = 1,50
Intégration électronique : 8 × 15 % = 1,20
Qualité d’affichage : 9 × 20 % = 1,80
Maintenance : 8 × 10 % = 0,80
Pérennité : 7 × 10 % = 0,70
Documentation : 8,5 × 5 % = 0,425

Score total = 8,225 / 10
Score arrondi = 8,2 / 10

---

## 4. Points forts constatés

- 
- 
- 

## 5. Points faibles constatés

- 
- 
- 

## 6. Risques restant ouverts

- 
- 
- 

## 7. Impact sur Project CRP

### Architecture mécanique

Conclusion :

### Architecture électrique

Conclusion :

### Refroidissement

Conclusion :

### Maintenance

Conclusion :

### Évolutivité et pérennité

Conclusion :

---

## 8. Décision

- [ ] Écran validé
- [X] Écran validé sous réserve
- [ ] Tests complémentaires nécessaires
- [ ] Écran rejeté

Justification :
Après essais, l’écran Elecrow 5 pouces 1024×600 obtient un score pondéré de **8,2 / 10**.

Il est validé comme **candidat prioritaire pour Project CRP**, sous réserve de validation mécanique finale.

Réserves :

- consommation électrique réelle non encore mesurée ;
- câbles droits HDMI, USB-C et audio incompatibles avec la profondeur cible ;
- nécessité probable de câbles coudés ou d’une solution d’adaptation interne ;
- intégration mécanique à confirmer dans FreeCAD ;
- protection obligatoire des nappes FPC ;
- validation finale à réaliser après conception du gabarit mécanique.

Actions suivantes :

1. remplir SYNTHESE-ET001.md
2. mettre à jour ET001-Ecran.md avec la décision “validé sous réserve” 
3. préparer le gabarit FreeCAD du module Elecrow.

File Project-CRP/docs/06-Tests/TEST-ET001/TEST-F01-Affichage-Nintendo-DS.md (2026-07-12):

# Project CRP – TEST-F01 – Affichage Nintendo DS

Version : 0.1  
Statut : réalisé
Étude associée : ET001 – Module d’affichage  
Composant testé : Elecrow 5inch IPS HD Display-C 1024×600  
Référence attendue : DLH04950B  
Plateforme : Raspberry Pi 5 – 4 Go  
Système : Batocera  

---

## 1. Objectif

Évaluer la lisibilité et l’ergonomie de la Nintendo DS sur l’écran de 5 pouces.

## 2. Dispositions à tester

- écrans l’un au-dessus de l’autre ;
- écrans côte à côte ;
- écran principal agrandi et secondaire réduit ;
- écran unique avec changement par bouton.

## 3. Résultats

| Disposition | Lisibilité principal | Lisibilité secondaire | Confort | Note globale |
|---|---:|---:|---:|---:|
| Verticale |  |  |  |  |
| Côte à côte |  |  |  |  |
| Principal agrandi |  |  |  |  |
| Écran unique |  |  |  |  |

## 4. Contrôles

| Contrôle | Résultat |
|---|---|
| Texte lisible | Oui |
| Écrans suffisamment grands | Oui |
| Changement de disposition accessible | Oui |
| Absence de déformation | Oui |
| Performances suffisantes | Oui |
| Tactile utilisable | Oui, avec melonDS |

## Observation sauvegarde Nintendo DS

Après installation des fichiers BIOS Nintendo DS requis, le jeu Pokémon DS fonctionne correctement au relancement après sauvegarde.

Résultat :

- jeu lancé : oui ;
- sauvegarde interne créée : oui ;
- fermeture propre de l’émulateur : oui ;
- relance après sauvegarde : oui ;
- erreur de communication après relance : non après ajout des BIOS ;
- cause probable du problème initial : BIOS / firmware Nintendo DS manquants.

Conclusion :

Le problème observé n’était pas lié au module d’affichage Elecrow.  
Le test Nintendo DS peut reprendre avec un environnement logiciel corrigé.

## 5. Conclusion

Disposition préférée : haut d'abord 

Note globale sur 10 : 8

Résultat : Acceptable avec réserve

Réserve :
Le confort Nintendo DS dépend fortement de la disposition des écrans et de l’émulateur utilisé.  
Le tactile est fonctionnel avec `melonDS`.

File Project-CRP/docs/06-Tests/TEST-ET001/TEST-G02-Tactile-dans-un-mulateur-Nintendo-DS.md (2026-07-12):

# Project CRP – TEST-G02 – Tactile dans un émulateur Nintendo DS

Version : 0.1  
Statut : réalisé – réussi avec réserve
Étude associée : ET001 – Module d’affichage  
Composant testé : Elecrow 5inch IPS HD Display-C 1024×600  
Référence attendue : DLH04950B  
Plateforme : Raspberry Pi 5 – 4 Go  
Système : Batocera  

---

## 1. Objectif

Vérifier l’utilisation du tactile dans les jeux Nintendo DS.

## 2. Procédure

1. Lancer un jeu nécessitant le stylet.
2. Tester des pressions précises.
3. Tester des glissements.
4. Changer la disposition des deux écrans.
5. Refaire les mêmes actions.

## 3. Résultats

| Contrôle | Conforme | Remarque |
|---|---|---|
| Position du toucher correcte |  |  |
| Réactivité suffisante |  |  |
| Glissements reconnus |  |  |
| Absence de décalage important |  |  |
| Fonctionnement après changement de disposition |  |  |

| USB-C écran connecté au Raspberry Pi | Oui |
| Nouveau périphérique détecté dans /proc/bus/input/devices | Oui |
| Nom du périphérique tactile | QDtech MPI5001 |
| Handler détecté |  event0 |
| Type d’entrée | Coordonnées absolues |
| Réaction tactile dans Batocera | Oui |
| Réaction tactile dans jeu DS | Oui après changement emulateur (melonDS)|
| Calibration nécessaire | À confirmer |

## Résultat TEST-G02 – Tactile dans un émulateur Nintendo DS

Jeu testé :  
Émulateur initial : autre cœur DS / configuration initiale non retenue
Émulateur validé : melonDS  

Le tactile physique de l’écran est détecté par Batocera sous le nom `QDtech MPI5001`.

Avec l’émulateur initial, le stylet DS pouvait être contrôlé au joystick, mais ni la souris USB ni le tactile physique de l’écran ne fonctionnaient dans le jeu.

Après passage à l’émulateur `melonDS`, le tactile physique fonctionne correctement dans le jeu Nintendo DS.

Résultat :

| Contrôle | Conforme | Remarque |
|---|---|---|
| Périphérique tactile détecté par Batocera | Oui | `QDtech MPI5001` |
| Toucher simple reconnu dans le jeu DS | Oui | Avec melonDS |
| Position du toucher correcte | Oui  |  |
| Glissement reconnu | Oui |  |
| Réactivité suffisante | Oui  |  |
| Fonctionnement via souris USB | Non  | Non fonctionnel avec l’émulateur initial |
| Fonctionnement via joystick | Oui | Fonctionnel avec l’émulateur initial |
| Fonctionnement après changement d’émulateur | Oui | melonDS |

## 4. Conclusion

Résultat : Réussi avec réserve
Réserve : confort Nintendo DS dépendant de la disposition d’écran et de l’émulateur utilisé.

Le tactile Nintendo DS est validé avec `melonDS`.

Réserve :

Le tactile physique n’est pas validé avec tous les émulateurs DS disponibles. Pour Project CRP, `melonDS` devient l’émulateur recommandé pour les tests Nintendo DS nécessitant le tactile.

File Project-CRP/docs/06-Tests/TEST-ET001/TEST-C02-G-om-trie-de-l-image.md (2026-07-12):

# Project CRP – TEST-C02 – Géométrie de l’image

Version : 0.1  
Statut : réalisé
Étude associée : ET001 – Module d’affichage  
Composant testé : Elecrow 5inch IPS HD Display-C 1024×600  
Référence attendue : DLH04950B  
Plateforme : Raspberry Pi 5 – 4 Go  
Système : Batocera  

---

## 1. Objectif

Vérifier l’absence d’étirement, de recadrage et de déformation.

## 2. Image de référence

Utiliser une mire comprenant :

- un cercle ;
- un carré ;
- une grille ;
- une bordure sur chaque côté ;
- du texte de petite taille.

## 3. Résultats

| Contrôle | Conforme | Remarque |
|---|---|---|
| Le cercle reste circulaire | Oui  |  |
| Le carré reste carré | Oui |  |
| Les quatre bordures sont visibles | Oui |  |
| L’image est centrée | Oui |  |
| Aucun recadrage | Oui |  |
| Aucun étirement horizontal | Oui |  |
| Aucun étirement vertical | Oui |  |
| Texte net et lisible | Oui |  |

## 4. Critère de réussite

Aucune déformation gênante ne doit être visible.

## 5. Conclusion

Résultat : Réussi

Remarques :

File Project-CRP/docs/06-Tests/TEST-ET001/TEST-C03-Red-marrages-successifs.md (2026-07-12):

# Project CRP – TEST-C03 – Redémarrages successifs

Version : 0.1  
Statut : réalisé
Étude associée : ET001 – Module d’affichage  
Composant testé : Elecrow 5inch IPS HD Display-C 1024×600  
Référence attendue : DLH04950B  
Plateforme : Raspberry Pi 5 – 4 Go  
Système : Batocera  

---

## 1. Objectif

Vérifier que l’affichage revient de manière fiable après plusieurs arrêts et démarrages.
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

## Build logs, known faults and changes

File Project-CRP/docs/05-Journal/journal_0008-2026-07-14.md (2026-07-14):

# Project CRP – Journal de développement 0008

Date : 14 juillet 2026  
Statut : gabarit mécanique écran Elecrow démarré  
Sujet principal : création du gabarit FreeCAD du module écran Elecrow

---

# 1. Contexte

Après la réalisation de la majorité des tests ET001 sur l’écran Elecrow 5 pouces 1024×600, le test `TEST-J01 – Consommation électrique de l’écran` reste reporté dans l’attente d’un testeur USB.

En attendant cette mesure électrique, la suite logique du projet est le passage à l’intégration mécanique.

La décision prise est donc de démarrer le **gabarit mécanique FreeCAD de l’écran Elecrow**.

Ce gabarit ne constitue pas encore une coque de console.  
Il sert uniquement de référence mécanique fiable pour préparer les futures étapes de conception.

---

# 2. Objectif du gabarit

L’objectif du gabarit est de représenter fidèlement le module écran reçu afin de sécuriser la conception mécanique de Project CRP.

Le gabarit doit permettre de vérifier :

- l’encombrement réel du module ;
- la position des trous de fixation ;
- la position de la zone visible de l’écran ;
- la présence des pattes de fixation ;
- l’épaisseur réelle du module ;
- les zones fragiles liées aux nappes FPC ;
- l’encombrement des connecteurs ;
- le dégagement nécessaire pour les câbles ;
- la compatibilité future avec une coque cible de 25 à 30 mm d’épaisseur.

Rappel important :

> Le gabarit n’est pas une pièce finale.  
> Il sert à éviter de concevoir la console autour d’une représentation fausse de l’écran.

---

# 3. Données mécaniques retenues

Les mesures issues des tests ET001 sont utilisées comme base prioritaire.

| Élément | Valeur retenue |
|---|---:|
| Largeur totale du module | 121,31 mm |
| Hauteur totale du module | 95,47 mm |
| Épaisseur retenue | 13 mm |
| Hauteur du rectangle écran physique | 75,65 mm |
| Zone active visible approximative | environ 108 × 64,8 mm |
| Diamètre des trous de fixation | 3 mm |

La valeur d’épaisseur a été corrigée pendant la préparation du gabarit.

L’estimation précédente de 10 mm est remplacée par la mesure réelle suivante :

> Épaisseur retenue du module écran : 13 mm.

Cette mesure inclut le module écran complet, son PCB arrière et les composants saillants.

---

# 4. Référence de coordonnées

Pour documenter les trous de fixation, le repère documentaire suivant est retenu :

```text
Origine documentaire : coin supérieur gauche du module
Axe X : vers la droite
Axe Y : vers le bas

Le premier gabarit FreeCAD représente l’encombrement principal de l’écran et les points de fixation.

Les nappes FPC, connecteurs et volumes de dégagement des câbles ne sont pas encore modélisés.  
Ils seront ajoutés dans une version ultérieure du gabarit sous forme de zones interdites ou de volumes de réservation.

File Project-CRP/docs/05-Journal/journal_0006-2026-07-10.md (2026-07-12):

# Project CRP – Journal de développement 0002

Date : 10 juillet 2026  
Statut : étude ET001 en cours  
Sujet principal : sélection et commande du module d’affichage

# Installation du Raspberry PI 5 KIT de chez db-tronic

J'ai essayé de faire fonctionné le système de sauvegarde sur pokemon or heart gold.
J'ai réalisé les tests de E03 à H03 qui me semble rassurant.
J'ai rencontré quelques problèmes avec le tactile (récupérer après un changement d'emulateur => melonds)

# Project CRP – Journal de développement 0007

Date : 10 juillet 2026  
Statut : essais ET001 en cours  
Sujet principal : validation de l’écran Elecrow, Nintendo DS, tactile et mesures complémentaires

---

# 1. Contexte

Les premiers composants du banc de test ont été reçus, notamment l’écran Elecrow 5 pouces destiné à l’étude ET001.

Les essais ont porté sur :

- l’identification réelle du module reçu ;
- les dimensions mécaniques ;
- le fonctionnement sous Batocera ;
- l’émulation Nintendo DS ;
- le tactile ;
- les BIOS Nintendo DS ;
- les premières réflexions sur la consommation électrique.

---

# 2. Dimensions réelles du module Elecrow

Le module reçu a été mesuré manuellement.

Dimensions relevées :

| Élément | Valeur mesurée |
|---|---:|
| Longueur horizontale totale | 121,31 mm |
| Hauteur totale du module | 95,47 mm |
| Profondeur approximative | 10 mm |
| Hauteur du rectangle écran | 75,65 mm |

Ces mesures montrent que le plan mécanique précédemment trouvé, indiquant notamment une hauteur de 77,93 mm, ne correspond pas au module reçu.

Le plan est donc classé comme :

> Document potentiellement utile, mais non correspondant au module reçu.

---

# 3. Analyse mécanique mise à jour

La hauteur totale de 95,47 mm semblait initialement contraignante pour une façade cible d’environ 110 mm.

Cependant, une analyse plus fine montre qu’environ 18 à 20 mm semblent correspondre à une zone technique supérieure, probablement liée aux fixations, au PCB ou à l’électronique, et non à la zone visible de l’écran.

La distinction suivante est retenue :

| Zone | Dimension approximative | Rôle |
|---|---:|---|
| Module complet | 121,31 × 95,47 mm | encombrement interne total |
| Rectangle écran | 121,31 × 75,65 mm | zone physique principale de l’écran |
| Zone active visible | environ 108 × 64,8 mm | image réellement affichée |

Conclusion :

- l’encombrement interne complet reste de 95,47 mm ;
- la façade visible n’a pas besoin d’exposer toute cette hauteur ;
- la zone technique peut probablement être cachée derrière la coque ;
- le module reste mécaniquement intéressant pour Project CRP.

La note mécanique provisoire de l’Elecrow est corrigée à :

> 8/10

---

# 4. Résolution et affichage sous Batocera

Le test de résolution a été réalisé.

La commande `xrandr` n’est pas disponible sur l’image Batocera utilisée pour Raspberry Pi 5.

La commande Batocera adaptée est :

```bash
batocera-resolution listModes

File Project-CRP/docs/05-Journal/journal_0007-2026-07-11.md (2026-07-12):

# Project CRP – Journal de développement 0002

Date : 11 juillet 2026  
Statut : étude ET001 en cours  
Sujet principal : sélection et commande du module d’affichage

# Installation du Raspberry PI 5 KIT de chez db-tronic

J'ai réalisé les test I01. N'ayant pas pour le moment de testeur USB, je reporte le test.

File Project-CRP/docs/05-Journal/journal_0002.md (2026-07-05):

# Project CRP – Journal de développement 0002

Date : 5 juillet 2026  
Statut : étude ET001 en cours  
Sujet principal : sélection et commande du module d’affichage

---

# 1. Contexte

L’étude technique ET001 porte sur le choix du module d’affichage de Project CRP.

Trois candidats principaux ont été étudiés :

1. Raspberry Pi Touch Display 2 – 5 pouces ;
2. Waveshare 5inch 720×1280 LCD ;
3. Elecrow 5inch IPS HD Display-C 1024×600.

L’objectif de cette étape était de comparer les caractéristiques techniques, l’intégration mécanique, l’intégration électronique, la maintenance, la pérennité et l’impact global de chaque solution sur Project CRP.

---

# 2. Méthode de comparaison

La matrice de décision provisoire utilise les pondérations suivantes :

| Critère | Pondération |
|---|---:|
| Compatibilité Raspberry Pi | 20 % |
| Intégration mécanique | 20 % |
| Intégration électronique | 15 % |
| Qualité d’affichage | 20 % |
| Maintenance | 10 % |
| Pérennité | 10 % |
| Documentation | 5 % |
| Prix | 0 % – informatif uniquement |

Le prix n’intervient pas encore dans la décision technique.

La qualité, la fiabilité, la maintenance et la pérennité sont prioritaires.

---

# 3. Décision concernant le candidat Elecrow

Le module suivant est retenu comme candidat prioritaire pour les essais :

**Elecrow 5inch IPS HD Display-C 1024×600**

Référence étudiée :

**DLH04950B**

Cette sélection n’est pas encore une validation définitive.

Le module Elecrow devient le candidat favori provisoire en raison de :

- son orientation native en paysage ;
- sa résolution de 1024×600 ;
- sa dalle IPS ;
- sa luminosité annoncée ;
- sa faible consommation annoncée ;
- son interface HDMI standard ;
- son alimentation USB-C ;
- ses dimensions mécaniques favorables ;
- sa documentation disponible ;
- sa facilité de test sur un banc indépendant.

---

# 4. Vérification du plan mécanique

Un plan coté du module Elecrow a été retrouvé et examiné.

Les dimensions suivantes ont été relevées :

| Dimension | Valeur |
|---|---:|
| Largeur hors tout | 121,11 ± 0,2 mm |
| Hauteur hors tout | 77,93 ± 0,2 mm |
| Zone active | 108 × 64,8 mm |
| Profondeur maximale | 13,94 ± 0,2 mm |
| Épaisseur de la partie principale | 7,66 ± 0,2 mm |

La valeur commerciale d’environ 10 mm trouvée précédemment ne représente donc pas l’encombrement maximal complet.

Pour la future CAO, une profondeur réservée de **15 à 16 mm** devra être prévue autour du module afin d’intégrer :

- les tolérances ;
- les composants les plus hauts ;
- les connecteurs ;
- les fixations ;
- une marge de sécurité ;
- l’absence de contact entre le PCB et la coque.

La hauteur réelle de 77,93 mm est favorable pour la cible mécanique de Project CRP, estimée autour de 110 mm.

---

# 5. Classement provisoire

À la suite de l’analyse du plan mécanique, l’Elecrow devient le candidat présentant le meilleur compromis provisoire.

Classement actuel :

1. Elecrow 5inch IPS HD Display-C 1024×600 ;
2. Raspberry Pi Touch Display 2 – 5 pouces ;
3. Waveshare 5inch 720×1280 LCD.

Ce classement reste provisoire.

Les notes finales seront recalculées après les essais matériels.

---

# 6. Compatibilité Batocera

La compatibilité générale de Batocera avec le Raspberry Pi 5 est considérée comme acquise pour la plateforme.

Cependant, la page de compatibilité Batocera ne permet pas de valider directement un modèle particulier d’écran HDMI.

La compatibilité réelle du module Elecrow doit donc être vérifiée expérimentalement.

Les principaux points à valider sont :

- démarrage de Batocera sur l’écran ;
- détection de la résolution 1024×600 ;
- fonctionnement à 60 Hz ;
- absence de déformation ;
- absence de recadrage ;
- absence de scintillement ;
- lisibilité de l’interface EmulationStation ;
- comportement des émulateurs ;
- utilisation Nintendo DS ;
- fonctionnement du tactile ;
- fonctionnement du second port HDMI ;
- basculement vers un téléviseur ;
- comportement après redémarrage.

---

# 7. Décision de réaliser un banc de test

Il a été décidé de ne pas valider définitivement l’écran sur la seule base des fiches techniques et des avis disponibles.

Un banc de test réel sera construit autour du matériel cible de Project CRP.

Le banc doit reproduire au minimum :

- le Raspberry Pi 5 4 Go ;
- le refroidissement actif ;
- l’alimentation officielle du Raspberry Pi ;
- Batocera sur carte microSD ;
- l’écran Elecrow ;
- une liaison micro-HDMI vers HDMI ;
- une alimentation USB indépendante pour l’écran ;
- une manette USB ou Bluetooth ;
- un téléviseur pour le test de la seconde sortie HDMI.

---

# 8. Matériel déjà disponible

Les éléments suivants sont déjà disponibles :

- manette PlayStation 4 ou PlayStation 5 ;
- câble USB-A vers USB-C ;
- chargeur de téléphone USB pouvant être utilisé pour l’alimentation séparée de l’écran, sous réserve de fournir au minimum 5 V / 1 A.

La manette sera utilisée en USB lors des premiers essais afin d’éviter qu’un éventuel problème Bluetooth ne perturbe la validation de l’affichage.

---

# 9. Commande du matériel

La commande du matériel nécessaire au banc de test a été lancée.

Livraison prévue :

**mardi 7 juillet 2026**

Le contenu exact de la commande devra être vérifié à la réception.

Les éléments attendus pour le test comprennent notamment :

- Raspberry Pi 5 4 Go ;
- système de refroidissement actif ;
- alimentation USB-C adaptée au Raspberry Pi 5 ;
- carte microSD ;
- câble micro-HDMI vers HDMI ;
- module d’affichage Elecrow 5 pouces 1024×600.

Un second câble micro-HDMI vers HDMI pourra être nécessaire pour tester simultanément :

- l’écran interne Elecrow ;
- la sortie vers un téléviseur.

---

# 10. Décision actuelle

La décision actuelle est la suivante :

> Le module Elecrow DLH04950B est retenu comme candidat prioritaire pour la phase de prototype et de validation expérimentale.

Cette décision ne constitue pas encore une sélection définitive pour Project CRP.

La sélection définitive dépendra des résultats du protocole d’essai.

---

# 11. Critères de validation

Le module pourra être validé si les essais confirment :

- un démarrage fiable sous Batocera ;
- une résolution native correcte ;
- une image sans défaut visible ;
- une luminosité suffisante ;
- une latence acceptable ;
- une température raisonnable ;
- une consommation compatible avec l’objectif d’autonomie ;
- une intégration mécanique possible ;
- un câblage interne réalisable ;
- une sortie TV fonctionnelle ;
- une maintenance simple ;
- un comportement stable après plusieurs cycles d’arrêt et de redémarrage.

---

# 12. Risques encore ouverts

Les risques suivants restent ouverts :

- configuration manuelle éventuelle du mode 1024×600 ;
- compatibilité avec certaines versions de Batocera ;
- encombrement réel des câbles HDMI et USB ;
- rayon de courbure des câbles ;
- épaisseur totale avec les connecteurs branchés ;
- disponibilité à long terme du module ;
- comportement du tactile sous Batocera ;
- comportement de la double sortie HDMI ;
- consommation réelle selon la luminosité ;
- qualité réelle de l’affichage ;
- lisibilité des jeux Nintendo DS sur 5 pouces.

---

# 13. Prochaine étape

La prochaine étape principale sera l’exécution du protocole de validation ET001 à la réception du matériel.

En attendant la livraison, les travaux documentaires, logiciels et mécaniques préparatoires peuvent continuer sans prendre de décision irréversible.

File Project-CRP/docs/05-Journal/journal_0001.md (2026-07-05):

# Project CRP - Journal de développement

## Journal n°0001

**Date :** 05 juillet 2026

---

# Début du projet

Aujourd'hui marque le lancement officiel de **Project CRP (Console Retro Plus)**.

L'objectif du projet est de concevoir une console portable de rétrogaming moderne, basée sur un Raspberry Pi 5, offrant une expérience proche d'une console du commerce tout en restant entièrement documentée, réparable et reproductible.

Dès le début du projet, il a été décidé que la priorité ne serait pas la compacité maximale, mais la qualité de conception, l'ergonomie et la maintenance.

---

# Objectifs initiaux

Les objectifs retenus sont les suivants :

* développer une console portable fiable ;
* utiliser Batocera comme système principal ;
* assurer une autonomie cible d'environ 6 heures ;
* permettre une utilisation sur téléviseur grâce à un dock dédié ;
* documenter intégralement le projet sur GitHub.

---

# Choix techniques validés

## Carte principale

Le Raspberry Pi 5 (4 Go) est retenu comme plateforme principale.

Motivations :

* performances adaptées au rétrogaming ;
* excellente compatibilité avec Batocera ;
* Wi-Fi et Bluetooth intégrés ;
* large communauté.

---

## Logiciel

Batocera est retenu comme système principal.

Motivations :

* simplicité d'utilisation ;
* grand nombre d'émulateurs intégrés ;
* excellente compatibilité avec le Raspberry Pi 5.

---

## Écran

Le projet utilisera un écran IPS de 5 pouces.

Ce format constitue un bon compromis entre confort de jeu, consommation électrique et dimensions générales de la console.

---

## Ergonomie

La console ne cherchera pas à reproduire exactement les dimensions d'une Nintendo Switch.

Les dimensions cibles sont volontairement légèrement supérieures afin de privilégier :

* le confort pour les grandes mains ;
* une meilleure maintenance ;
* une intégration plus simple des composants.

Dimensions provisoires :

* largeur : 245 à 255 mm ;
* hauteur : environ 110 mm ;
* épaisseur : 25 à 30 mm.

---

## Commandes

La disposition retenue comprend :

* un D-Pad ;
* quatre boutons ABXY ;
* deux joysticks Hall Effect ;
* Start ;
* Select ;
* Volume + / - ;
* Power ;
* L1/L2 ;
* R1/R2.

Le choix a été fait de limiter volontairement le nombre de boutons afin d'éviter les appuis accidentels et de conserver une bonne ergonomie.

---

## Batterie

Les objectifs retenus sont :

* environ 6 heures d'autonomie ;
* recharge USB-C Power Delivery ;
* possibilité de jouer pendant la recharge ;
* batterie facilement remplaçable.

La capacité définitive sera déterminée après les calculs de consommation et le choix des composants.

---

## Dock

Le dock est volontairement simple.

Fonctions prévues :

* alimentation de la console ;
* recharge de la batterie ;
* sortie HDMI vers un téléviseur ;
* LED indiquant la présence de l'alimentation.

Le choix a été fait de ne pas intégrer de ports USB supplémentaires dans la première version.

---

## Refroidissement

La console intégrera un ventilateur.

Le contrôle intelligent de sa vitesse sera prévu, mais restera une fonctionnalité optionnelle pouvant être activée ou désactivée.

---

## Boîtier

Le boîtier sera imprimé en PETG.

Les objectifs principaux sont :

* robustesse ;
* démontage facile ;
* maintenance rapide ;
* remplacement simple des composants principaux.

---

# Philosophie du projet

Plusieurs principes de développement ont été adoptés dès le lancement :

* documenter toutes les décisions ;
* privilégier la qualité à la compacité ;
* utiliser des composants standards ;
* limiter les soudures au strict nécessaire ;
* rendre le projet facilement reproductible.

Le projet sera développé de manière incrémentale, chaque étape étant validée avant de passer à la suivante.

---

# Organisation du dépôt GitHub

Le dépôt GitHub devient la source officielle de toutes les informations du projet.

Chaque évolution importante devra être accompagnée :

* d'une mise à jour de la documentation ;
* d'un journal de développement ;
* d'une mise à jour de la nomenclature si nécessaire.

---

# Prochaine étape

La prochaine phase du projet consistera à définir l'architecture générale de la console.

Les travaux porteront notamment sur :

* l'implantation des composants ;
* le système d'alimentation ;
* le cheminement des câbles ;
* la stratégie de maintenance ;
* les interfaces entre les différents modules.

---

## État du projet

Le projet entre officiellement en phase de conception.

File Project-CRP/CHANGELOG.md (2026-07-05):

# Changelog

- Initial commit: structure du projet.

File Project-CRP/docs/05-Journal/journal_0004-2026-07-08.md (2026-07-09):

# Project CRP – Journal de développement 0002

Date : 8 juillet 2026  
Statut : étude ET001 en cours  
Sujet principal : sélection et commande du module d’affichage

# Installation du Raspberry PI 5 KIT de chez db-tronic

J'ai effectué l'installation du boitier dans sa globalité. Je n'ai pas mis en place de carte PCIe comme dans la vidéo sur le site du constructeur, car je n'en avais pas.
J'ai également installé l'image de l'OS Raspberry PI 5, tout me semble fonctionnelle.
J'ai également branché ma souris. Elle fonctionne.
J'ai branché une manette PS4 où je vois le voyant de contact marché mais l'utilisation des boutons ne donnes rien.
J'ai également connecté en bluetooth un clavier qui fonctionne correction.
Ensuite j'ai paramétré les valeurs de température de mon ventilateur avec les informations suivantes (dans le fichier config.txt présent dans le dossier boot/firmware):
- dtparam=fan_temp0=65000
- dtparam=fan_temp0_hyst=8000
- dtparam=fan_temp0_speed=75

- dtparam=fan_temp1=70000
- dtparam=fan_temp1_hyst=8000
- dtparam=fan_temp1_speed=128

- dtparam=fan_temp2=75000
- dtparam=fan_temp2_hyst=8000
- dtparam=fan_temp2_speed=192

- dtparam=fan_temp3=80000
- dtparam=fan_temp3_hyst=8000
- dtparam=fan_temp3_speed=255

Il se lance au démarrage, puis s'arrête. Je verrais plus tard, si en chauffant, le ventilateur se met en route.

# Installation du Batocera

Je passe donc à l'installation de Batocera (version bcm2712-43.1-20260529).
Et je m'aperçois en lisant la documentation qu'on ne peut pas sur une même clé mettre un flash de Batocera et l'os Raspberry. N'ayant qu'une seul carte mémoire ce soir. Je décidé de la réinitialisé pour mettre Batocera.

Après installation de Batocera, tout fonctionne mais je pense que je vais devoir paramétrer la manette. Je me suis arrété à l'étape 9 du document CRP-Preparation-Raspberry-Pi-5-ET001.md.
Prochaine étape, tester l'écran.

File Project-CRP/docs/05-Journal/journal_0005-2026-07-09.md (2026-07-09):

# Project CRP – Journal de développement 0002

Date : 9 juillet 2026  
Statut : étude ET001 en cours  
Sujet principal : sélection et commande du module d’affichage

# Installation du Raspberry PI 5 KIT de chez db-tronic

J'ai ouvert la boite de l'écran.
J'ai installé d'abord l'écran sur mon pc portable tout va bien.
J'ai ensuite installé l'écran sur le port micro hmdi 2 (ne semble pas fonctionné).
J'ai ensuite installé l'écran sur le port micro hmdi  1 qui fonctionne.
J'ai joué au jeu dongkey kong. Tout me semble opérationnel. 
Je m'arrête ce matin 8:05 au test B02.

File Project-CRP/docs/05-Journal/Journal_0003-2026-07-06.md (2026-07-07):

# Project CRP – Journal de développement 0003

Date : 6 juillet 2026  
Statut : préparation des essais ET001  
Sujet principal : préparation du gabarit mécanique et du cahier de tests

---

# 1. Contexte

La livraison des premiers composants du banc de test est attendue pour le mardi 7 juillet 2026.

En attendant leur arrivée, le travail devait initialement porter sur la création du gabarit mécanique du module d’affichage Elecrow dans FreeCAD.

L’objectif était de préparer un modèle 3D simplifié du module, sans commencer la coque définitive de Project CRP.

---

# 2. Choix du logiciel de CAO

Le logiciel retenu pour la conception mécanique de Project CRP est :

**FreeCAD**

Ce choix est motivé par les points suivants :

- logiciel libre ;
- gratuit ;
- disponible sur plusieurs systèmes d’exploitation ;
- adapté à un projet open source ;
- capable de produire des modèles 3D paramétriques ;
- possibilité d’exporter les modèles dans des formats standards comme STEP et STL.

---

# 3. Ajout au glossaire

Une entrée a été ajoutée au glossaire du projet.

## CAO — Conception Assistée par Ordinateur

La CAO désigne l’utilisation d’un logiciel pour concevoir, dessiner et vérifier des pièces ou des assemblages en deux ou trois dimensions.

Dans Project CRP, la CAO sera notamment utilisée pour créer :

- le gabarit mécanique de l’écran ;
- la coque de la console ;
- les supports internes ;
- les emplacements des boutons et des sticks ;
- les passages de câbles ;
- les trous de fixation ;
- le dock.

Une CAO détaillée ne doit être réalisée qu’à partir de dimensions fiables et vérifiées.

---

# 4. Réévaluation du plan mécanique de l’écran

Lors de la comparaison entre le plan mécanique précédemment trouvé et les photographies commerciales du module Elecrow commandé, un doute important est apparu concernant la correspondance exacte des deux modèles.

Les différences possibles concernent notamment :

- la forme du PCB ;
- la position des connecteurs ;
- le nombre et la position des boutons OSD ;
- les trous de fixation ;
- l’encombrement arrière ;
- la référence exacte du module.

Le cartouche du plan ne permet pas de confirmer avec certitude qu’il correspond au modèle `DLH04950B`.

---

# 5. Décision concernant le gabarit mécanique

Il a été décidé de ne pas commencer un gabarit mécanique détaillé avant la réception et l’identification du module réel.

Le plan précédemment trouvé est désormais classé comme :

> Document potentiellement correspondant, non validé.

Les dimensions suivantes ne sont donc plus considérées comme confirmées pour le produit commandé :

- largeur hors tout de 121,11 mm ;
- hauteur hors tout de 77,93 mm ;
- profondeur maximale de 13,94 mm ;
- position des trous de fixation ;
- position exacte des connecteurs.

Ces dimensions pourront servir de points de comparaison, mais pas de base définitive pour FreeCAD.

---

# 6. Règle appliquée

La décision respecte les principes de Project CRP :

- ne pas créer de complexité sans bénéfice démontré ;
- ne pas figer une implantation mécanique à partir d’informations incertaines ;
- valider les composants structurels par des données fiables ;
- conserver une traçabilité des hypothèses et des corrections ;
- éviter un travail de CAO qui devrait être entièrement refait.

---

# 7. Travail retenu en attendant les composants

À la place du gabarit mécanique détaillé, il a été décidé de préparer le protocole de validation de l’écran.

Le protocole couvre notamment :

- l’identification du module ;
- la correspondance avec le plan mécanique ;
- la mise sous tension ;
- le premier affichage ;
- la résolution 1024×600 ;
- la géométrie de l’image ;
- la stabilité après redémarrage ;
- la luminosité ;
- les couleurs et le contraste ;
- les angles de vision ;
- la fluidité ;
- l’interface Batocera ;
- les jeux rétro ;
- l’émulation Nintendo DS ;
- le tactile ;
- la sortie TV ;
- la double sortie HDMI ;
- la stabilité thermique ;
- la consommation ;
- les dimensions mécaniques ;
- les fixations ;
- l’encombrement des connecteurs.

---

# 8. Création du cahier de tests ET001

Le protocole unique a été divisé en 25 fiches indépendantes afin de faciliter l’exécution progressive, la saisie des résultats, la maintenance documentaire et l’utilisation dans GitHub.

## Identification et inspection

- `TEST-A01` — Identification du module
- `TEST-A02` — Comparaison avec le plan mécanique

## Premier démarrage

- `TEST-B01` — Mise sous tension de l’écran
- `TEST-B02` — Premier affichage avec le Raspberry Pi

## Résolution et géométrie

- `TEST-C01` — Détection de la résolution
- `TEST-C02` — Géométrie de l’image
- `TEST-C03` — Redémarrages successifs

## Qualité d’affichage

- `TEST-D01` — Luminosité
- `TEST-D02` — Couleurs, contraste et uniformité
- `TEST-D03` — Angles de vision
- `TEST-D04` — Fluidité et rémanence

## Utilisation sous Batocera

- `TEST-E01` — Interface EmulationStation
- `TEST-E02` — Jeux rétro au format 4:3
- `TEST-E03` — Jeux au format large

## Nintendo DS

- `TEST-F01` — Affichage Nintendo DS

## Tactile

- `TEST-G01` — Détection et calibration du tactile
- `TEST-G02` — Tactile dans un émulateur Nintendo DS

## Sortie TV

- `TEST-H01` — Sortie vers un téléviseur seul
- `TEST-H02` — Double sortie HDMI
- `TEST-H03` — Déconnexion et reconnexion du téléviseur

## Stabilité et consommation

- `TEST-I01` — Fonctionnement prolongé et température
- `TEST-J01` — Consommation électrique de l’écran

## Relevé mécanique

- `TEST-K01` — Dimensions principales du module
- `TEST-K02` — Fixations du module
- `TEST-K03` — Connecteurs et composants saillants

---

# 9. Documents complémentaires générés

Deux documents complémentaires ont été ajoutés :

- `README.md`, qui définit l’ordre recommandé des essais et les règles de validation ;
- `SYNTHESE-ET001.md`, qui regroupe les résultats, les notes expérimentales, les risques et la décision finale.

Le dossier est prévu dans :

`docs/06-Tests/ET001-Ecran/`

---

# 10. Ordre de test recommandé à la réception

1. identification du module ;
2. comparaison avec le plan ;
3. inspection des connecteurs ;
4. mise sous tension de l’écran seul ;
5. premier affichage avec le Raspberry Pi ;
6. détection de la résolution ;
7. contrôle de la géométrie ;
8. redémarrages successifs ;
9. qualité d’image ;
10. Nintendo DS ;
11. sortie TV ;
12. relevé mécanique.

Les tests de consommation pourront être reportés si aucun testeur USB n’est disponible.

---

# 11. Décisions enregistrées

## DEC-ET001-008

Le plan mécanique trouvé n’est pas considéré comme validé tant que le module reçu n’a pas été comparé visuellement et mesuré.

Statut : validée.

## DEC-ET001-009

Le gabarit mécanique FreeCAD détaillé est suspendu jusqu’à la réception du composant réel.

Statut : validée.

## DEC-ET001-010

La validation de l’écran sera réalisée à l’aide de fiches de tests indépendantes et traçables.

Statut : validée.

## DEC-ET001-011

Le relevé mécanique réel du module aura priorité sur les dimensions commerciales ou les plans non identifiés.

Statut : validée.

---

# 12. Risques ouverts

- réception d’une variante différente du modèle étudié ;
- absence de référence claire sur le PCB ;
- plan mécanique non correspondant ;
- résolution 1024×600 nécessitant une configuration manuelle ;
- tactile non reconnu par Batocera ;
- problème de double sortie HDMI ;
- câbles trop encombrants pour la future coque ;
- profondeur réelle supérieure aux valeurs annoncées ;
- fixation mécanique difficile ;
- consommation réelle différente de la valeur constructeur.

---

# 13. Prochaine étape

À la réception des composants :

1. vérifier le contenu de la commande ;
2. exécuter `TEST-A01` ;
3. exécuter `TEST-A02` ;
4. ne commencer le gabarit FreeCAD qu’après validation ou correction des dimensions ;
5. poursuivre les essais électriques et logiciels selon le cahier ET001.

---

# 14. Commit proposé

```text
docs: journalise la préparation du cahier de tests ET001
```

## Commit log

2026-07-05 Add initial specifications for Project CRP
    This document outlines the specifications and objectives for the Project CRP, a retro gaming console based on Raspberry Pi 5, including hardware features, connectivity, and design philosophy.
2026-07-05 Document RP2040 integration strategy and prototypes
    Added integration strategy for RP2040 and prototype details.
2026-07-05 Add electrical architecture documentation for Project CRP
    This document outlines the general electrical architecture of Project CRP, detailing the various electrical modules, their responsibilities, and communication interfaces. It serves as a functional re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
2026-07-05 Add mechanical architecture documentation for Project CRP
    This document outlines the general mechanical architecture of Project CRP, detailing component layout, assembly principles, airflow strategy, and maintenance approach. It serves as a reference for th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
2026-07-12 corrige et consolide les résultats des tests ET001
